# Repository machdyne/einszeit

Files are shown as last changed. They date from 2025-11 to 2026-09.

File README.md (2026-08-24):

# Einszeit

Einszeit is an open-source security device intended to provide information-theoretically secure (one-time-pad based) encryption between two or more paired devices over any communications medium.

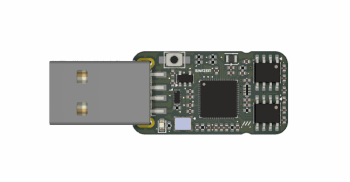
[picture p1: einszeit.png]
Einszeit


> **Project status:** V1 hardware is in active development. See [Hardware Status](#hardware-status) and [Software Status](#software-status) below before using this project for anything beyond bench testing.

## Hardware Status

| Version | Status |
|---|---|
| V0 | **Deprecated.** Based on the ATSHA204A secure element. See [Why V0 was deprecated](#why-v0-was-deprecated). No longer maintained or recommended for use. |
| V1 | **Design complete, not yet fabricated.** Redesigned around the RP2350 microcontroller. Boards have not yet been fabricated, bench validated, entropy-tested, or used to generate production key material. |

### Why V0 was deprecated

V0 relied on the ATSHA204A secure element's `Random` command as its sole entropy source. While this was suitable for a functional prototype, it is not a raw entropy tap — it is the output of an internal DRBG (deterministic random bit generator) seeded periodically from a physical noise source. This means:

- Output entropy is bounded by the (infrequently refreshed) internal seed, not by the number of bytes read out.
- The construction is architecturally unsuited to one-time-pad key material, which requires each output bit to carry close to full entropy.
- The DRBG design is closed and proprietary, offering no way to independently validate its internal construction. (still true on V1 unfortunatey)

### V1 architecture (hardware)

V1 is built around the **RP2350** microcontroller, chosen primarily for its documented, dedicated TRNG peripheral.

- **Entropy source:** RP2350's built-in TRNG block (Arm IP), which samples an internal free-running ring oscillator and claims compliance with FIPS 140-2, BSI AIS-31, and NIST SP 800-90B. Nominal entropy rate is ~7.5 kb/s at 150 MHz core clock.
- **Key storage:** key material now never leaves the device and can now be exchanged on a microsd card

A secondary, physically independent entropy source (e.g. a discrete noise circuit) is not currently planned, but remains a possible future defense-in-depth addition if the RP2350 TRNG's characteristics warrant it.

Full entropy source documentation, extraction method, and validation results will be published alongside V1 firmware.

## Software Status

The `ez` utility (originally written against V0's alice/bob device model) is **not yet compatible with V1**.

- V1 introduces a **multi-key model**, replacing the fixed alice/bob key-pair scheme with support for multiple paired devices and key slots.
- `ez` will require updated firmware-side commands and a corresponding rewrite of its identity, key-copy, and read/write logic to address multiple key slots rather than a single fixed pair.
- New V1 firmware (implementing the TRNG-based generation pipeline and multi-key metadata format) is in progress and not yet released.

## Security Model

Einszeit's core claim is that, given genuine full-entropy key material and correct one-time use, message confidentiality is information-theoretically secure — i.e., secure regardless of an adversary's computational power. This claim depends entirely on:

1. The entropy source(s) actually delivering full min-entropy per output bit (not merely passing statistical randomness tests, which a well-built DRBG would also pass).
2. Conditioning/extraction functions that don't reintroduce a computational-hardness dependency where an information-theoretic one is claimed (e.g., preferring universal-hash/Leftover-Hash-Lemma-based extraction over hash-based conditioning where the strict claim matters).
3. Correct one-time use of key material and secure erasure after use.

## AI Disclosure

This project makes use of LLMs for documentation, specifications, firmware and software. Once the project is stable, a human audit will be performed resulting in a code freeze that must not be directly modified by any LLM without an additional human audit.

## Funding

This project was partially funded through the NGI0 Commons Fund, a fund established by NLnet with financial support from the European Commission's Next Generation Internet programme.

## License

The contents of this repo are released under the [CERN-OHL-P](LICENSE.txt) license with the following exceptions:

 * The ch32fun library is MIT licensed.
 * The hidapi library is BSD licensed.

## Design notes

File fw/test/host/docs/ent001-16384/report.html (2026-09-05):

# Einszeit V1 hardware validation

conditioned.bin · 100,800,000 bits · conditioned mode

Device 9bae095b4556f8f4 · RP2350 OTP CHIPID, unique per die

0.8791

bits of min-entropy per captured bit
Compression is the limiting estimator

01.0, a perfect binary source

At this rate, one byte of one-time-pad key needs 9.1 bits (1.14 raw bits per key bit) fed through a conditioning function that preserves min-entropy.

Capture mode

conditioned

SP 800-90B

0.8791 bit/bit

SP 800-22

15/15 pass, 1 marginal

AIS-31 (2011)

all pass

FIPS 140-2 4.9.1

5040 blocks

This capture is the conditioned TRNG output. Passing statistical tests on conditioned data says very little: a correctly seeded DRBG passes all of them too. The min-entropy figure above is an upper bound on what the post-processing preserved, not a measurement of the physical source. Use a raw capture for the entropy claim.

## Entropy assessment

Assessed over 8,000,000 bits using the non-IID track of SP 800-90B. The reported min-entropy is the smallest of the ten estimators, which is what the specification requires.

Each estimator bounds min-entropy from above in its own way; the assessment takes the most pessimistic.

Each estimator bounds min-entropy from above in its own way; the assessment takes the most pessimistic.

Estimator | Hmin | Note
Most Common Value | 0.9984
Collision | 0.9753
Markov | 0.9970
Compression | 0.8791
t-Tuple | 0.9295
LRS | 0.9982
MultiMCW | 0.9992
Lag | 0.9980
MultiMMC | 0.9989
LZ78Y | 0.9989

Assessed on the first 8,000,000 bits of a 100,800,000-bit capture. SP 800-90B asks for at least 1,000,000 samples and the predictors scale badly beyond a few million; SP 800-22 below was run over the full capture. Override with --entropy-bits.

The Compression estimator is limiting, but it is reporting at its ceiling for this sample size. Running the same estimator over an ideal uniform sample of 8,000,000 bits scores 0.8807 ± 0.0113 (mean of 5 runs), against 0.8791 measured. The gap of 0.0016 is within normal run-to-run spread, so at this length the estimator cannot report higher and this figure reflects the estimator rather than the source. Capture more to raise the ceiling.

### Independence indicators

Check | Statistic | p
Chi-square goodness of fit | 9.92 | 0.3567
Chi-square independence | 4.91 | 0.0857
Longest repeated substring | 44 | expected 45.9

consistent with IID. These indicators can reject IID but cannot establish it. A formal IID claim requires the 10,000-permutation test from SP 800-90B 5.1, which is not reimplemented here.

## Distribution and structure

Measure | Value | Reference
Capture size | 12,600,000 B | 100,800,000 bits
Proportion of ones | 0.500006 | 0.5
Bit bias | +0.000006 | 0
Shannon entropy per bit | 1.000000 | 1.0
Shannon entropy per byte | 7.999978 | 8.0
Min-entropy per byte, most common value | 7.9805 | 8.0
Byte chi-square | 377.6 | 255 ± 23, p = 0.0000
Arithmetic mean of bytes | 127.4730 | 127.5
Monte Carlo π | 3.14299 | error 0.045%
Serial correlation | -0.000795 | 0
Longest run of ones / zeros | 25 / 23 | ~27
Compressed size (zlib / bz2 / lzma) | 1.0003 / 1.0050 / 1.0001 | ≥ 1.0

Visual inspection. Any visible texture, banding or repetition is a defect that the numeric tests may not isolate.

Visual inspection. Any visible texture, banding or repetition is a defect that the numeric tests may not isolate.

Byte value distribution against the uniform expectation.

Byte value distribution against the uniform expectation.

Bias by position inside one 192-bit entropy-holding-register read. A repeating shape here points at the collection mechanism rather than the ring oscillator.

Bias by position inside one 192-bit entropy-holding-register read. A repeating shape here points at the collection mechanism rather than the ring oscillator.

Autocorrelation at short lags. A spike at a fixed lag usually means the sampling interval is short enough that consecutive samples share oscillator phase.

Autocorrelation at short lags. A spike at a fixed lag usually means the sampling interval is short enough that consecutive samples share oscillator phase.

Power spectrum. Peaks indicate periodic structure, often from a clock beating against the ring oscillator.

Power spectrum. Peaks indicate periodic structure, often from a clock beating against the ring oscillator.

Run lengths against the 2^-k ideal.

Run lengths against the 2^-k ideal.

Entropy across the capture, in order.

Entropy across the capture, in order.

## Standards conformance

### NIST SP 800-22 Rev 1a, 100 sequences

This is the governing SP 800-22 result: the suite partitioned into 100 sequences of 1,008,000 bits, scored by the proportion of sequences passing. Tests that emit several p-values per sequence are scored per sub-test, as the specification intends; the count column shows how many, and the proportion shown is the worst of them.

Test | sub | worst | proportion vs bound | Result
Approximate entropy | | 100/100 | 1.000 vs 0.960 | pass
Binary matrix rank | | 99/100 | 0.990 vs 0.960 | pass
Block frequency | | 100/100 | 1.000 vs 0.960 | pass
Cumulative sums | 2 | 100/100 | 1.000 vs 0.960 | pass
DFT (spectral) | | 99/100 | 0.990 vs 0.960 | pass
Frequency (monobit) | | 100/100 | 1.000 vs 0.960 | pass
Linear complexity | | 100/100 | 1.000 vs 0.960 | pass
Longest run of ones | | 99/100 | 0.990 vs 0.960 | pass
Maurer universal | | 100/100 | 1.000 vs 0.960 | pass
Non-overlapping template | 10 | 97/100 | 0.970 vs 0.960 | pass
Overlapping template | | 100/100 | 1.000 vs 0.960 | pass
Random excursions | 8 | 62/64 (36 seq n/a) | 0.969 vs 0.953 | pass
Random excursions variant | 18 | 63/64 (36 seq n/a) | 0.984 vs 0.953 | pass
Runs | | 96/100 | 0.960 vs 0.960 | marginal
Serial | 2 | 97/100 | 0.970 vs 0.960 | pass

Marginal: Runs. The shortfall is smaller than one sequence, which is the integer coarseness of the acceptance bound rather than evidence of a defect.

### Single-sequence pass over the first 20,000,000 bits

A second, independent run of the same suite treating the first 20,000,000 bits as one sequence. It is not the conformance result; it is kept because a single long sequence has more statistical power than any individual sequence above, so it can surface a small consistent deviation that the per-sequence view absorbs. Disagreement between the two is expected and is not a contradiction.

Test | p | Result
Frequency (monobit) | 0.9797 | pass
Block frequency | 0.9914 | pass
Runs | 0.0000 | fail
Longest run of ones | 0.8280 | pass
Binary matrix rank | 0.9651 | pass
DFT (spectral) | 0.7257 | pass
Non-overlapping template | 0.5223 | pass | 10 p-values, min 0.0218
Overlapping template | 0.4007 | pass
Maurer universal | 0.9706 | pass
Linear complexity | 0.8327 | pass
Serial | 0.7001 | pass | 2 p-values, min 0.7001
Approximate entropy | 0.4107 | pass
Cumulative sums | 0.9298 | pass | 2 p-values, min 0.9131
Random excursions | 0.4293 | pass | 8 p-values, min 0.0795
Random excursions variant | 0.6374 | pass | 18 p-values, min 0.0923

p-values from the single-sequence pass; they should scatter roughly uniformly over (0,1).

p-values from the single-sequence pass; they should scatter roughly uniformly over (0,1).

Runs failed the single-sequence pass above but not the 100-sequence assessment. Test power grows with sequence length, so a small consistent deviation can sit inside the threshold on each shorter sequence and clear it over a longer one. The conformance verdict follows the multi-sequence result; the disagreement is recorded here because it is the more sensitive of the two and is worth investigating even when conformance is met.

### BSI AIS-31

Proc | Test | Value | Accept | Result
A | T0 disjointness | 65536.000 | 65536 – 65536 | pass
A | T1 monobit | 9984.000 | 9654 – 10346 | pass
A | T2 poker | 9.843 | 1.03 – 57.4 | pass
A | T3 runs | — | | pass
A | T4 long run | 16.000 | 0 – 33 | pass
A | T5 autocorrelation | 2553.000 | 2326 – 2674 | pass
B | T6 uniform distribution | 0.503 | 0.475 – 0.525 | pass
B | T7 comparative multinomial | 248.512 | | pass
B | T8 entropy (Coron) | 7.999 | 7.976 – 8 | pass

Implements AIS 31 v2.0 (2011). BSI's AIS 20/31 v3.0 (2024) restructures these procedures; a v3.0 evaluation needs different tests.

### FIPS 140-2 section 4.9.1

Across 5,040 blocks of 20,000 bits. A few blocks fall outside the intervals by chance on any source, so each subtest is judged on whether its failure count matches the expected false-positive rate.

Test | blocks failed | expected | p | Result
monobit | 1 | 0.5 | 0.396 | pass
poker | 1 | 0.5 | 0.396 | pass
runs | 0 | 1.8 | 1.000 | pass
long_run | 0 | 1.0 | 1.000 | pass

FIPS 140-2 4.9.1 is a power-up self-test on a single 20,000-bit block. Applied across a large capture, a few blocks fall outside its intervals by chance, so each subtest is judged on whether its failure count matches the expected false-positive rate rather than on a clean sweep. Removed from FIPS 140-2 by the 2002 change notice and absent from FIPS 140-3.

## SEC-TEST-ENT-001 conformance

EZ-SEC-001 requires the SP 800-22 suite, all fifteen tests, to be run against at least 100,000,000 bits of TRNG output for each hardware revision. This analysis is satisfied by this analysis.

Requirement | Result | Measured
At least 100,000,000 bits of TRNG output | met | 100,800,000 bits
All 15 tests executed | met | 15 of 15 produced a result
All tests pass | met | all pass
Proportion criterion meaningful (m >= 100) | met | 100 sequences
p-value uniformity applicable (m >= 50) | met | 100 sequences

This is a conformance statement from an independent reimplementation of SP 800-22. For the formal record, run NIST's sts-2.1.2 against the archived capture and cite that result; see EZ-TEST-DEVIATIONS.md G-04.

## Board subsystems

### Pin integrity

Each pin read with the internal pull-up then the internal pull-down engaged. A pin with an external pull-up reads high in both states, because 10K or 20K overwhelms the RP2350's ~55K internal pull-down. That is how the external resistors are confirmed present.

Pin | Net | pull-up | pull-down | Result
GPIO18 | FRAM_SCLK | 1 | 0 | pass
GPIO19 | FRAM_MOSI | 1 | 0 | pass
GPIO20 | FRAM_MISO | 1 | 0 | pass
GPIO21 | FRAM_SS | 1 | 1 | pass
GPIO25 | SD_DET | 1 | 1 | pass
GPIO26 | SD_SCLK | 1 | 1 | pass
GPIO27 | SD_MOSI | 1 | 1 | pass
GPIO28 | SD_MISO | 1 | 1 | pass
GPIO29 | SD_CSN | 1 | 1 | pass
GPIO12 | LED | 1 | 0 | pass

### Clocks

Clock | Configured | Measured
clk_sys | 150.000 MHz | 150.000 MHz
clk_peri | 48.000 MHz | 48.000 MHz
clk_usb | 48.000 MHz | 48.000 MHz
XOSC | — | 12.000 MHz
ROSC | — | 44.035 MHz
LPOSC | — | 33 kHz
XOSC stable | — | yes

### Always-on timer

Tick source | internal LPOSC (untrimmed ~32 kHz)
Running | yes
Measured error | 19799.2 ppm over 5000 ms

The RP2350 has no RTC block; this is the POWMAN always-on timer. When its tick comes from the same 12 MHz crystal as the system timer, the error above measures the divider and not the crystal, so it will read near zero regardless of crystal accuracy. Only a comparison against an external reference characterises the crystal itself.

### FRAM

present | True
rdid_supported | False
wel_toggles | True
miso_alive | True
id | 000000000000000000
vendor | unknown
part | unknown
density_bytes | 0
sr_idle | 0
sr_wren | 2
sr_wrdi | 0
test_ok | True
test_id_ok | False
test_sr_ok | True
test_bus_ok | True
test_patterns_ok | True
test_addressing_ok | True
test_bytes_tested | 28672
test_errors | 0
test_first_error_addr | 0

### microSD

ok | True
step | 9
step_name | ready
last_r1 | 0
acmd41_iterations | 3
init_ms | 8
type | SDHC/SDXC
capacity_bytes | 31666995200
blocks | 61849600
ocr | 0xc0ff8000
oid
pnm | APPSD
psn | 0x12800000
mdt | 2012-04

## Provenance

This capture is characterisation data and must not be used as key material. It was produced by bench firmware that bypasses the TRNG health tests, and it has crossed a USB link to this host. EZ-SEC-001 SEC-ENTROPY-001 requires key bytes to come exclusively from the TRNG on the device, and SEC-DIST-001 prohibits electronic transmission of key material.

Identifier | Value | Notes
Device UUID | 9bae095b4556f8f4 | RP2350 OTP CHIPID0..3, a 64-bit identifier programmed at manufacture. Read through the ROM get_sys_info call, so it identifies the die and not the flash part. The datasheet treats it as a public device ID.

The block below is telemetry the device recorded alongside the capture itself: die temperature, system clock, TRNG configuration and health-test counters. It travels inside every capture and is present whether or not the subsystem tests were run.

Everything above derives from the capture described here. Re-running the analysis on the archived .bin reproduces this report exactly.

{
  "key_material": false,
  "usage": "TEST ONLY - characterisation data, MUST NOT be used as key material (EZ-SEC-001 SEC-ENTROPY-001, SEC-DIST-001)",
  "fw": "einszeit-hwtest",
  "version": "1.4.0",
  "kind": "capture",
  "mode": "conditioned",
  "device_uuid": "9bae095b4556f8f4",
  "board_id": "9bae095b4556f8f4",
  "rosc_len": 0,
  "sample_cnt": 16384,
  "bypass_vnc": false,
  "bypass_crngt": false,
  "bypass_autocorr": false,
  "bytes": 17088,
  "collections": 712,
  "vn_err": 0,
  "crngt_err": 8,
  "autocorr_err": 0,
  "resets": 0,
  "timeouts": 0,
  "elapsed_us": 60296821,
  "bits_per_sec": 2267.18,
  "temp_c_start": 32.29,
  "temp_c_end": 32.29,
  "clk_sys_hz": 150000000,
  "rows": 0,
  "row_bytes": 0,
  "rounds": 65,
  "total_bytes": 12600000,
  "concatenated": true,
  "_container": {
    "declared_crc32": "0x00000000",
    "computed_crc32": "0x00000000",
    "crc_ok": true,
    "payload_bytes": 12600000
  }
}

### What this report does not establish

- The estimators here are an independent reimplementation of SP 800-90B, not a validated one. A certification claim needs NIST's own EntropyAssessment tool against the same archived capture.
- Restarts are triggered by TRNG_SW_RESET rather than by power-cycling the noise source, which is weaker than the specification intends.
- Entropy was measured at one supply voltage and one die temperature. A source that is healthy at room temperature can degrade at the edges of its range; characterise across the intended operating envelope before trusting it with key material.
- The TRNG is closed Arm IP. No amount of output testing can rule out a construction that is deterministic in a way the tests cannot see. This is the same limitation the project documentation notes for V0.

Generated 2026-09-05 10:02:33 CEST by einszeit-hwtest. Capture CRC-32 verified end to end from device to this report.

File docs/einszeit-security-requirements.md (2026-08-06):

# Einszeit Security Requirements Specification

**Document ID:** EZ-SEC-001  
**Status:** Normative  
**Scope:** All Einszeit hardware, firmware, software, interfaces, and documentation

---

## 0. Foundational Principle

One-Time Pad (OTP) encryption provides **information-theoretic (perfect) secrecy** if and only if three invariants hold simultaneously:

1. **Key length ≥ plaintext length** — the key is never shorter than the data it encrypts.
2. **Key is truly random** — key material is generated from a true random source, not a PRNG.
3. **Key is never reused** — each key byte is consumed exactly once, across all sessions, devices, and time.

Any violation of any invariant completely and irrecoverably destroys secrecy. All requirements in this document exist to enforce these three invariants at every layer of the system.

> **Physical and host security scope:** This specification does not address attacks that require physical access to the device or a compromised host. If an attacker controls the host machine, they can read plaintext directly (e.g., via keylogger). While devices may have some physical security features, protection against such attacks is ultimately the user's responsibility.

> **Authentication scope:** This specification covers encryption and decryption only. Message authentication — verifying that a message was produced by the expected party — is out of scope. The Key ID is a coordination identifier, not a secret, and MUST NOT be used as an authenticator or as evidence of message origin.

---

## 1. Definitions

| Term | Meaning |
|---|---|
| **Key** | A block of OTP key material generated once, distributed physically, and consumed over its lifetime. Identified by a Key ID. |
| **Key ID** | A TRNG-generated unique identifier associated with a Key at creation time. Not a secret. Used to differentiate between multiple shared keys, and by the device to identify sessions locally. |
| **Session** | A device's local record of its use of a specific Key, referenced by Key ID. Stores the current offset, role, drive index, human-readable name, and session status. Each Key has exactly one session per device; multiple sessions on one device correspond to multiple distinct Keys. |
| **Session status** | A flag stored in the session record indicating the session's operational state. Valid values: `VALID` (healthy and operational), `QUARANTINED` (integrity check failed; locked pending user action), `EXHAUSTED` (all key bytes consumed). Additional implementation-defined states (e.g. for optional features) may exist; see EZ-IMPL-001. |
| **Role** | A per-session designation of `alice` or `bob`, determining which half of the key the party consumes. Alice consumes from offset 0; bob consumes from `key_length / 2`. The key generator defaults to alice; the recipient defaults to bob. |
| **OTP offset** | The byte position of the next unconsumed key byte within a Key. Stored per-session in metadata storage. |
| **Key data storage** | Non-volatile storage holding key material (e.g., flash or removable media). |
| **Metadata storage** | High-endurance non-volatile storage holding session state (offsets, IDs, names). Logically and physically separate from key data storage. |
| **Plaintext** | Data before encryption. |
| **Ciphertext** | `Plaintext XOR key_bytes_at_offset`. |
| **TRNG** | True Random Number Generator — hardware entropy source producing non-deterministic output. |
| **PRNG** | Pseudo-Random Number Generator — a software algorithm producing deterministic output from a seed. **Never** used to generate key material. |
| **DRNG** | Deterministic Random Number Generator — a hardware component that produces output deterministically from a seed, regardless of how the seed was obtained. Produces pseudo-random, not truly random, output. **Never** used to generate key material. |
| **CSPRNG** | Cryptographically Secure Pseudo-Random Number Generator — a software algorithm producing deterministic output from a seed, designed to be computationally unpredictable. **Never** used to generate key material. |
| **Party** | One of the two endpoints sharing a Key. |

---

## 2. Entropy and Key Generation

### 2.1 Source Requirements

- **SEC-ENTROPY-001:** Key bytes MUST be generated exclusively from a hardware TRNG. Key material MUST NOT contain contributions from DRNGs, PRNGs, or CSPRNGs, regardless of whether they are implemented in hardware or software.
- **SEC-ENTROPY-002:** The TRNG MUST produce a minimum of 8 bits of entropy per output byte. Post-generation statistical testing MUST be performed on every generated key before it is marked valid and made available for use (see §9.1). A key MUST NOT be marked valid unless it passes these tests. If testing fails, the key MUST be discarded and the generation event logged as failed.
- **SEC-ENTROPY-003:** TRNG output MUST NOT be conditioned or whitened by any algorithm that could introduce determinism. If hardware debiasing is applied, it MUST NOT reduce per-byte entropy below 8 bits.
- **SEC-ENTROPY-004:** The TRNG MUST fail safe: generation MUST halt and raise an auditable fault if the entropy source is detected as degraded or unavailable. The system MUST NOT fall back to any software source.

### 2.2 Generation Process

- **SEC-GEN-001:** Key bytes MUST be transferred from the TRNG to key data storage without buffering in volatile memory longer than necessary to write a single block. Volatile buffers MUST be cleared immediately after each write.
- **SEC-GEN-002:** Key data MUST be verified by read-back immediately after writing, within the same generation session.
- **SEC-GEN-003:** Each generation event MUST produce a new Key ID (TRNG-generated) and record a generation log entry (timestamp, Key ID, byte length, test results) in metadata storage. The log entry MUST record whether the key was marked valid or rejected.

### 2.3 Online Entropy Monitoring (Recommended)

Online monitoring during generation is not required if the firmware guarantees that no key can be marked valid without passing post-generation tests (SEC-ENTROPY-002). It is RECOMMENDED as a way to detect TRNG degradation early and minimise wasted generation time.

If implemented, online monitoring SHOULD apply at minimum the following tests on a rolling window, halting generation immediately on failure:

- Monobit frequency test (proportion of 1s in the window)
- Runs test (length of consecutive identical bits)
- Autocorrelation test (correlation of output with a shifted copy of itself)

---

## 3. Storage Architecture

The system uses two logically and physically distinct storage tiers with strictly separated roles:

| Tier | Contents |
|---|---|
| Key data storage | Key material — raw random bytes only; Key ID is associated out-of-band via filename or manual exchange |
| Metadata storage | Session records: Key ID, role, drive index, OTP offset, session status, human-readable name |

These tiers MUST NOT be swapped. Key material MUST NOT be written to metadata storage. Session metadata MUST NOT be written to key data storage.

### 3.1 Key Data Storage

- **SEC-STORE-001:** Key data storage MUST support erasure under firmware control. The firmware is solely responsible for all write and erase policies.
- **SEC-STORE-002:** Each Key MUST have a Key ID associated with it at creation time. The Key ID MUST be generated by the TRNG and MUST NOT be derived from or related to the key material bytes. The Key ID is conveyed out-of-band (via filename convention or manual exchange) and is not embedded in the key file. It is used to differentiate between multiple shared keys and to correlate key data with a session record in metadata storage.

### 3.2 Metadata Storage

Metadata storage MUST support byte-level or word-level writes with high endurance, making OTP offset updates atomic and efficient. The choice of medium is an implementation decision; the requirements below apply regardless.

- **SEC-META-001:** Each session record MUST contain at minimum: Key ID, role, drive index, key length, two OTP offset slots, an offset selector, session status, human-readable name, and a CRC or equivalent integrity check covering the entire record.
- **SEC-META-002:** OTP offset updates MUST be written atomically. Power loss during an update MUST leave the offset in either the pre-update or post-update state — never in a partially updated state.
- **SEC-META-003:** On every power-on, all session records MUST be read and their integrity verified before any session operation is permitted. A session with a corrupt record MUST be set to `QUARANTINED` and flagged to the user. It MUST NOT silently reset its offset.
- **SEC-META-004:** Before allocating a new session record, the firmware MUST verify that its address range does not overlap any existing session record. Allocation MUST be rejected if a conflict is detected.

### 3.3 OTP Offset Integrity

The OTP offset is the most security-critical piece of metadata. Its corruption or rollback directly enables key reuse.

- **SEC-PTR-001:** The OTP offset MUST be stored with integrity protection per SEC-META-001. A corrupt offset MUST be detected on read and MUST NOT be silently treated as zero or any other default value.
- **SEC-PTR-002:** The OTP offset MUST only advance forward. Any command or request to set an offset to a value less than or equal to its current verified value MUST be rejected and logged.
- **SEC-PTR-003:** The offset MUST be advanced and the update committed atomically before ciphertext is output. If the update cannot be verified, the operation MUST be aborted and no ciphertext output.

---

## 4. Key Distribution

- **SEC-DIST-001:** Keys MUST be distributed via physical transfer only. Electronic transmission of key material over any network is PROHIBITED.
- **SEC-DIST-002:** A Key SHOULD be shared between exactly one alice and one bob. Distributing to multiple bobs is possible but they MUST be treated as read-only recipients — multiple bobs share the same offset range and any bob encrypting from it would cause immediate key reuse and irrecoverable loss of secrecy for all recipients. In a multi-bob scenario, any bob can also impersonate alice by encrypting from alice's offset range, and other bobs have no way to detect this. More broadly, any party holding key material can misuse it in this way; limiting distribution limits exposure.
- **SEC-DIST-003:** Upon receiving a Key, the recipient SHOULD verify the Key ID matches the expected value before importing it into a session. Mismatches SHOULD be investigated before proceeding.
- **SEC-DIST-004:** Unintended duplication of a Key creates additional parties who can decrypt all messages encrypted under that Key. The system cannot prevent duplication; users are responsible for controlling how many copies of a Key exist.
- **SEC-DIST-005:** If a medium carrying a Key shows evidence of unexpected access or tampering, the user MUST be warned. The decision to proceed or discard is the user's.

---

## 5. Encryption and Decryption

### 5.1 Encryption Operation

- **SEC-ENC-001:** Encryption MUST be performed as `C[i] = P[i] XOR K[offset + i]` for each byte `i` of the plaintext, where `offset` is the current OTP offset for the session. The initial offset is role-dependent: alice starts at 0, bob starts at `key_length / 2`.
- **SEC-ENC-002:** The OTP offset MUST be advanced and committed before ciphertext is output (SEC-PTR-003).
- **SEC-ENC-003:** Plaintext MUST NOT be written to any persistent storage. Plaintext buffers in volatile memory MUST be cleared immediately after ciphertext is produced.
- **SEC-ENC-004:** The message header MUST include the OTP offset at which encryption began, so the receiver can locate the correct key bytes. The offset is not a secret. Whether to include a Key ID in the header is a protocol decision left to the implementation.

### 5.2 Decryption Operation

- **SEC-DEC-001:** Decryption MUST be performed as `P[i] = C[i] XOR K[offset + i]`, where `offset` is taken from the message header.
- **SEC-DEC-002:** If a Key ID is present in the message header, the receiver MUST verify it matches the session's Key before reading any key bytes. If no Key ID is present, session selection is the responsibility of the operator or higher-level protocol.
- **SEC-DEC-003:** Replay detection: the receiver MUST reject any message whose offset range overlaps a previously consumed range. Rejection MUST occur before any key bytes are read or output is produced.
- **SEC-DEC-004:** After successful decryption, the receiver's OTP offset MUST advance to `max(current_offset, message_offset + message_length)`.

### 5.3 Key Derivation Prohibition

- **SEC-KDF-001:** Key derivation functions, key stretching, or any algorithmic transformation of key material MUST NOT be used. Key bytes MUST be used directly as the key stream.

### 5.4 Session Isolation

- **SEC-ISO-001:** Key bytes from one session MUST NOT be accessible during an operation belonging to another session. The firmware MUST enforce session boundaries so that loading key bytes for session A never reads from the offset range of session B.
- **SEC-ISO-002:** It is PROHIBITED for two sessions on the same device to share the same Key ID. Importing a Key whose Key ID already exists in a session record MUST be rejected.

---

## 6. Transmission

- **SEC-TX-001:** Ciphertext MAY be transmitted over any channel. Channel confidentiality is not required.
- **SEC-TX-002:** The message header MUST carry the OTP offset (SEC-ENC-004). No plaintext, key material, or session state beyond what is required by the header MUST appear in transmitted data.

---

## 7. User Interface

- **SEC-UI-001:** The UI MUST display the remaining key capacity for each session. Remaining capacity is half the total key length minus bytes consumed, since each party (alice or bob) has access to only their half of the key. When remaining capacity falls below a configurable threshold (default: 20%), a persistent warning MUST be shown. When a session is fully exhausted, the UI MUST notify the user and mark the session inactive.
- **SEC-UI-002:** Plaintext MUST NOT be retained in any scrollback buffer, clipboard, or undo history after the user dismisses the message view.
- **SEC-UI-003:** The UI MUST require explicit user confirmation before any encryption operation that advances the OTP offset, to prevent accidental key consumption.
- **SEC-UI-004:** Quarantined sessions (SEC-META-003) MUST be visually distinguished from healthy sessions and MUST NOT be usable for encryption or decryption until the user explicitly resolves or deletes them.
- **SEC-UI-005:** OTP offset values and remaining key length MUST NOT appear in any log file or diagnostic output accessible to a remote party. Key IDs may appear in logs as they are not secret.

---

## 8. Hardware Design Requirements

- **SEC-HW-001:** All OTP operations (generation, encryption, decryption) MUST be performed on the dedicated Einszeit device. These operations MUST NOT be delegated to or performed on a host computer.
- **SEC-HW-002:** If removable media is used as key data storage during active sessions, its removal is equivalent to loss of key material for those sessions. The firmware MUST detect removal and MUST NOT continue an in-progress encryption or decryption operation after removal.
- **SEC-HW-003:** If key data storage and firmware storage share the same physical medium, they MUST occupy non-overlapping address regions. A firmware write or update operation MUST NOT be able to reach the key data region.

---

## 9. Firmware and Software Requirements

- **SEC-FW-001:** All firmware MUST be written in a memory-safe language, or all memory safety vulnerabilities MUST be identified and remediated by code review.
- **SEC-FW-002:** All variables holding plaintext or key bytes MUST be handled in a way that prevents compiler optimization from eliding clearing operations (e.g., `volatile`-qualified writes or explicit memory barrier calls in C).
- **SEC-FW-003:** Any memory region that held key bytes or plaintext MUST be cleared before it is reused for any other purpose.
- **SEC-FW-004:** The firmware MUST NOT expose a command, interface, or debug path that allows raw read access to key data storage. All key data access MUST go through the session management layer, which enforces offset advancement.

---

## 10. Testing Requirements

### 10.1 Entropy Testing

- **SEC-TEST-ENT-001:** TRNG output MUST pass the NIST SP 800-22 statistical test suite (all 15 tests) on a minimum sample of 10⁸ bits, performed on each hardware revision and after any modification to the entropy source.
- **SEC-TEST-ENT-002:** If online entropy monitoring is implemented (§2.3), it MUST be verified by injecting a known-bad (biased) byte stream and confirming it triggers halt within one rolling window.
- **SEC-TEST-ENT-003:** The AIS-31 (BSI) test suite MUST be applied to characterise the TRNG output on each hardware revision.

### 10.2 OTP Offset Tests

- **SEC-TEST-PTR-001:** A test harness MUST verify that offset advancement is monotonic under normal operation, simulated power loss at each stage of the metadata write sequence, and concurrent session access attempts.
- **SEC-TEST-PTR-002:** A test harness MUST verify that a corrupt session record (bit-flip injection into metadata storage) is detected on power-on and causes the session to be quarantined rather than silently used.
- **SEC-TEST-PTR-003:** A test harness MUST verify that offset rollback attempts (by command or simulated storage manipulation) are rejected.

### 10.3 Encryption Correctness Tests

- **SEC-TEST-ENC-001:** Known-answer tests (KATs) MUST be run on every firmware build: given a fixed key and plaintext, verify ciphertext byte-for-byte.
- **SEC-TEST-ENC-002:** A test MUST verify that encrypting the same plaintext at two different OTP offsets produces different ciphertexts.
- **SEC-TEST-ENC-003:** A test MUST verify that re-encrypting at the same offset is impossible because the offset has already advanced.

### 10.4 Session Isolation Tests

- **SEC-TEST-ISO-001:** A test MUST verify that importing a Key whose Key ID already exists in a session record is rejected (SEC-ISO-002).
- **SEC-TEST-ISO-002:** A test with two active sessions MUST verify that a read for session A never returns bytes from session B's offset range.

### 10.5 Replay Tests

- **SEC-TEST-REPLAY-001:** A test MUST verify that a message with a previously consumed offset range is rejected before any key bytes are read or output is produced.

### 10.6 Removable Media Tests

- **SEC-TEST-MEDIA-001:** A test MUST verify that removing key storage media during an in-progress operation causes the operation to be aborted cleanly, with no partial ciphertext output and no offset advancement recorded.

---

## 11. Requirements Traceability

Every implementation artifact (hardware schematic, firmware module, test case, user manual section) MUST reference the requirement IDs it satisfies. No requirement may be marked satisfied by documentation alone; each MUST be demonstrated by a passing test (§10) or a physical inspection record.

---

*End of EZ-SEC-001*

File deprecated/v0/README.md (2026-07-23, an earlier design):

# Einszeit

Einszeit is an open-source security device that can theoretically provide perfect quantum-proof encryption between two paired devices over any communications medium.

Einszeit

This repo contains schematics, PCB layouts, a 3D-printable case, firmware and documentation.

Find more information on the [Einszeit product page](https://machdyne.com/product/einszeit-security-device/).

*V0 has been deprecated; see V1.*

## Limitations

Some of the limitations may be improved through firmware updates.

  * Message generation is limited to ~2MB after each pairing.
  * Initial key generation takes several hours.
  * Paired devices must be distributed in person.
  * Crypto IC configuration is factory locked to enable RNG output.
  * Key is temporarily stored on your computer during pairing.
  * Device is limited to ~400K lifetime metadata updates.
  * Must copy key to one device at a time.
  * Lacks fundamental error checking.

## Usage

The `ez` utility can be used to configure the device identity, to generate and copy keys, and to read or write messages. It stores the key pointer on the device, incrementing it each time a message is written.

### Set device identity

This command initializes the device metadata and sets the device identity.

Each device in the pair is identified as either alice or bob. The metadata is stored in EEPROM. The device must be erased to change its identity.

If the identity is alice, this command will also generate both the alice and bob keys and save them as `ez.key` (this will take several hours).

```
$ ez -i <alice|bob>
```

### Copy keys

This command copies the key data to the connected device.

```
$ ez -c
```

### Write a message

The write command generates an encrypted base64-encoded message. The message will only be generated after the key pointer has been successfully incremented.

```
$ ez -w << plain.txt
```

or

```
$ ez -w
Type your message here.
^D
```

### Read a message

Use this command to read an encrypted base64-encoded message that was previously generated using the write command from a paired device.

```
$ ez -r << cipher.txt
```

or

```
$ ez -r
Paste the base64-encoded message here.
^D
```

Note: You can use `-v` to verify a message that you've written.

### Erase device

This peforms a factory reset by erasing the keys and metadata.

```
ez -E
```

### Random data

This command will generate 32 bytes of random data, it can be used to test the quality of the hardware random number generator with testrand.sh.

```
ez -R
```

## Implementation Details

### Metadata

The metadata is 32-bytes and is stored in one of 16 EEPROM data slots:

	magic[2] = 0x455a
    sequence[4] = highest value indiciates current slot
	send_ptr[4] = offset of next unused key location
	boot_cnt[4] = incremented each time the device is powered on
	identity[1] = (0x00 = alice, 0x01 = bob)
    reserved[16]
	crc[1] = crc8(metadata)

All metadata slots are scanned to find the latest valid slot, then written to (latest\_slot + 1) % 16 on update.

*Note: This is currently limited to 4 slots.*

### Key Storage

The alice key is stored in flash at 0x000000 and the bob key is stored at 0x200000.

### Message Format

Messages are generated in the following format:

```
base64 ( [ <key_ptr:32> <msg_len:32> <ciphertext:n> ] <crc32:32> )
```

Note that the key offset and message length are not encrypted.

## LLM-generated code

To the extent that there is LLM-generated code in this repo, it should be space indented. Any space indented code should be carefully audited and then converted to tabs (eventually).

## License

The contents of this repo are released under the [CERN-OHL-P](LICENSE.txt) license, with the following exceptions:

  * The ch32fun library is MIT licensed.
  * The hidapi library is BSD licensed.

Note: You can use these designs for commercial purposes but we ask that instead of producing exact clones, that you either replace our trademarks and logos with your own or add your own next to ours.

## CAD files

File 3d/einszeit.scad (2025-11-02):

/*
 * Einszeit Enclosure
 * Copyright (c) 2025 Lone Dynamics Corporation. All rights reserved.
 *
 * required hardware:
 *  - 1 x M2.5 x 10mm countersunk bolt
 *  - 1 x M2.5 nut
 *
 */
 
$fn = 30;

box_width = 19;
box_length = 37;
box_height = 10.5;
box_thickness = 2.0;

lid_thickness = 3;

cutout_width = 16.10;
cutout_length = 44;
cutout_height = 5.5;

cutout_usb_width = 12;

board_height = 1.4;

roundness = 2;

toladj = 0.25;

//ldp_board(-0.5);
translate([0,0,-0.5]) ldp_case();
//translate([0,0,-0.25]) ldp_endcap();

// m2.5 bolt
//translate([0,-13.5,-6.25]) color([1,0,0]) cylinder(d=2.5, h=12, $fn=36);

// m2.5 nut
//translate([0,-13.5,-6.55]) rotate(30) color([1,0,0]) cylinder(d=5.8, h=2.4, $fn=6);

module ldp_endcap()
{
    		 	
	difference() {
		union() {
			translate([0,-13.5,-0.5]) color([0,0,1]) cylinder(d=6, h=3.5, $fn=36);
			translate([0,-15.75,-0.25]) cube([16.1,5.5,6.5], center=true);
		}
		translate([0,-13.5,-4.25]) color([1,0,0]) cylinder(d=3, h=8, $fn=36);
        color([1,0,0]) translate([0,0,-5.5]) cube([6.5,100,6], center=true);

	}
}

module ldp_board(o)
{

	difference() {
		union() {
			translate([0,2,o])
				color([0.0,0.8,0.0]) cube([16, 26, 1.6], center=true);
			translate([0,23,o+1])
				color([0.9,0.9,0.9]) cube([12, 15, 4.5], center=true);
		}

	}
	
}

module ldp_case()
{

	difference() {
		
		minkowski() {
			cube([box_width-(roundness*2),box_length-(roundness*2),box_height-(roundness*2)],
				center=true);
			sphere(roundness);
		}	
        
		translate([0,-5,(box_height-cutout_height)/2-2])
			cube([cutout_width+toladj,cutout_length,cutout_height], center=true);

		translate([-5.675,-5,(box_height-cutout_height)/2-3])
			cube([5,cutout_length,cutout_height], center=true);
		
		translate([5.675,-5,(box_height-cutout_height)/2-3])
			cube([5,cutout_length,cutout_height], center=true);

		// USB cutout
        translate([0,15,0.8])
            cube([cutout_usb_width+toladj,10,4.6+toladj], center=true);
        
		// bolt hole
		translate([0,-13.5,-5]) cylinder(d=2.75+toladj, h=100, $fn=36);
		
		// nut cutout
		translate([0,-13.5,-5.75]) rotate(30) cylinder(d=6+toladj, h=2.5, $fn=6);
    
        // lid notch cutout
        translate([0,-13.5,4.5]) cylinder(d=5+toladj, h=100);

//        translate([-1.5,2.5,5.1]) rotate([0,0,270])
//            linear_extrude(0.3)
//                text("EINSZEIT", size=3.5, halign="center", font="Lato Black");

	}

}

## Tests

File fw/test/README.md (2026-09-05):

# fw/test — Einszeit V1 hardware validation

Bring-up firmware and analysis tooling for the Einszeit V1 board (RP2350A).
Validates the HRNG, FRAM, microSD, clocks and board wiring, transfers entropy
captures over USB CDC with XMODEM-1K, and produces a report covering entropy
quality and the standards the RP2350 TRNG is claimed to meet.

> **This is a bench instrument, not a production artifact.** It deliberately
> bypasses the TRNG hardware health tests and exposes storage test paths. Never
> flash it to a device holding key material, and never include it in a build
> that generates key material. See `docs/EZ-TEST-DEVIATIONS.md`.

## Compliance status against EZ-SEC-001

This artifact is **not fully compliant, by design**. Three requirements are
deliberately inverted because inverting them is the tool's function: you cannot
characterise a noise source whose health tests halt it, and you cannot assess
raw entropy that has already been debiased.

- `docs/EZ-TEST-TRACEABILITY.md` — every requirement ID, its disposition, and
  the evidence for each satisfied row, per EZ-SEC-001 §11. Includes the
  SEC-FW-001 code review record.
- `docs/EZ-TEST-DEVIATIONS.md` — five deviations (D-01 … D-05) and six gaps
  (G-01 … G-06), each with a containment measure or an action.

Three gaps block a compliant *product*, not this tool: **G-04** (SP 800-22 at
10⁸ bits), **G-05** (online monitoring and per-key acceptance testing) and
**G-06** (the §10.2–10.6 harnesses, which need the session layer to exist).

The main control added by the audit is `src/ez_guard.c`: the firmware refuses
every storage read, write and erase path unless the FRAM is demonstrably blank
or carries this tool's own marker. On V1 the FRAM is metadata storage, holding
the OTP offsets. A bench tool that can roll an offset backwards causes silent
key reuse — the one failure EZ-SEC-001 §0 calls irrecoverable.

```
ez> fram test
refused: fram test

This board's FRAM holds data that is neither blank nor this tool's own test
marker. On a provisioned Einszeit device the FRAM is metadata storage: it holds
the OTP offsets that record how much of each Key has been consumed.
...
```

On a genuinely bare board, `guard claim` writes the marker and storage tests
become available.

## Layout

```
CMakeLists.txt      standalone or add_subdirectory(test) from fw/
include/  src/      firmware
host/               Python analysis and report tooling
docs/               EZ-SEC-001 audit records
```

## Build

```bash
mkdir build && cd build
PICO_SDK_PATH=/path/to/pico-sdk cmake .. -DCMAKE_BUILD_TYPE=Release
make -j
```

Or from `fw/CMakeLists.txt`, after the parent has called `pico_sdk_init()`:

```cmake
add_subdirectory(test)
```

Builds clean under `-Wall -Wextra`, which is part of the SEC-FW-001 evidence.
`-DEZ_ENABLE_RAW_STORAGE_DUMP=ON` re-enables the raw dump paths and knowingly
violates SEC-FW-004 and SEC-UI-005; CMake warns when you do it.

### Firmware update mode

Three ways in, no button needed for the first two:

```bash
python3 ez_validate.py bootsel --port /dev/ttyACM0   # from the host
```
```
ez> reboot bootsel                                    # from the device shell
```
```bash
picotool reboot -f -u                                 # works even if the shell hangs
```

`picotool` works without any cooperation from the firmware because the build
sets `PICO_STDIO_USB_ENABLE_RESET_VIA_VENDOR_INTERFACE=1`, which exposes a
reset endpoint alongside the CDC interface.

The board then enumerates as RPI-RP2 mass storage; copy
`build/einszeit_hwtest.uf2` to it, or `picotool load -x build/einszeit_hwtest.uf2`.
The status LED on GPIO12 keeps blinking in the bootloader as an activity
indicator, so you can tell the board is alive rather than hung.

Holding the BOOTSEL button while plugging in still works as the fallback.

Note that the card-detect policy and the storage guard release are held in RAM
only, so both revert on reboot. Re-apply them after an update, or make them
permanent in `board.h`.

## Run

```bash
cd host && pip install -r requirements.txt
./ez_validate.py selftest                  # check the tooling first
./ez_validate.py ports
./ez_validate.py all --port /dev/ttyACM0 --out runs/board-01
```

Produces `runs/board-01/report.html` (self-contained), `report.json`, and the
raw `.bin` captures so the analysis can be re-run or handed to NIST's tools.
A first pass takes about 15 minutes, most of it waiting on the TRNG.
`--sweep` and `--restart` add hours.

## Commands

```
help                            command list with capture examples
info [--json]                   chip, board id, clocks, die temperature
pins [--json]                   external pull-up verification (no SD card fitted)
guard [claim] [--json]          storage access policy; claim marks a blank board
led on|off|blink

clock [--json]                  clock tree, configured against measured
clock aon [ms] [--json]         always-on timer source and drift

fram id [--json]                JEDEC ID, vendor/part decode, status register
fram size [--json]              density by address aliasing        [guarded]
fram test [bytes] [--full]      patterns and address uniqueness     [guarded]
fram bench [bytes]              throughput at seven SPI clocks      [guarded]
fram dump <addr> <len>          disabled by default (SEC-FW-004, SEC-UI-005)
fram write <addr> <hex>                                             [guarded]

sd det [--watch]                card-detect level and transitions
sd init | sd info [--json]      SPI bring-up, CID/CSD decode        [needs card]
sd read <lba>                   read and CRC-verify; contents withheld
sd bench [blocks]               throughput and CRC errors           [needs card]
sd write <lba> --yes            destructive block write             [guarded]

hrng info [--json]              every TRNG register, decoded
hrng cfg [rosc N] [sample N] [raw|cond]
hrng health [n] [--json]        throughput and health-test error counters
hrng cap <bytes> [raw|cond] [rosc N] [sample N]
hrng sweep [collections] [raw]  chain length x sample interval, CSV
hrng restart <rows> <bytes>     SP 800-90B restart matrix

buf [zero]                      buffer status; 'buf zero' wipes and verifies
dump [n]                        hex dump of the capture buffer
send                            transmit the buffer over XMODEM-1K
selftest [--json]               every subsystem in one pass
reboot [bootsel]
```

Every command ends with `[done rc=N]` so a host script can frame the output.
`--json` emits one `#JSON {...}` line. Long operations emit `# progress` lines
and abort on ESC. `[guarded]` commands require `ez_guard_permit_storage()`.

## Capture modes

`cond` leaves the Von Neumann balancer, continuous RNG test and autocorrelation
test enabled — the configuration production firmware would use.

`raw` sets all three bypass bits in `TRNG_DEBUG_CONTROL`, giving raw digitised
ring-oscillator samples. This is what SP 800-90B assesses, and is deviation
D-02 against SEC-ENTROPY-003.

Captures are framed in a 1024-byte header carrying the exact payload length, a
CRC-32, and JSON metadata including `"key_material": false`. The length matters
because XMODEM pads its last block with 0x1A and pad bytes must never reach an
entropy estimator.

## Reading the entropy number

The report leads with min-entropy per captured bit and what follows from it:
how many raw bits you need per bit of one-time-pad key. At 0.35 bit/bit, a byte
of key needs about 23 bits of raw capture through a min-entropy-preserving
conditioner.

Two things to expect:

- **The raw capture will look bad.** Bias and short-lag correlation are normal
  for a directly sampled ring oscillator. That is why the hardware has a Von
  Neumann balancer in front of it.
- **The compression estimator often reads lowest.** Its expected-value curve is
  nearly flat near maximum entropy, so the 99% confidence subtraction costs a
  lot at small sample sizes. It converges slowly. The report flags this when it
  is the limiting estimator.

`SAMPLE_CNT1` resets to 65535, giving roughly 2.3 kbit/s at 150 MHz — well below
the ~7.5 kbit/s in the project README. Production firmware will need a shorter
interval, and shorter sampling costs sample independence. `--sweep` measures
that trade across all four inverter chain lengths.

## If `fram id` reports nothing

Two causes, both handled since 1.1.1:

**RDID is not universal.** The original Fujitsu MB85RS64 family, including the
MB85RS64PNF on Blaustahl, has no Device ID command, so opcode 0x9F clocks out
all zeroes from a perfectly healthy part. `fram id` now probes by toggling the
write-enable latch (WREN/WRDI, read back through RDSR), which every SPI FRAM
supports, and reports `PRESENT` even when the ID is unavailable. Use
`fram size` to measure density directly.

**Running `pins` first used to break the bus.** The pin test switches each GPIO
to SIO to read it, and before 1.1.1 it did not restore the SPI function
afterwards, so every later FRAM transfer returned 0x00. Fixed; function,
direction and level are now saved and restored per pin.

## FRAM identification: RDID is not universal

`fram id` does **not** use the JEDEC Device ID command to decide whether the
part is present, because not every SPI FRAM has one. The original Fujitsu
MB85RS64 family (including the MB85RS64PNF used on Blaustahl) predates RDID
entirely: sending 0x9F clocks out nothing and the host reads all zeroes, which
looks identical to a dead bus.

Presence is established instead by toggling the write-enable latch: `WREN` must
set WEL in the status register and `WRDI` must clear it. Every SPI FRAM ever
made supports RDSR and WREN/WRDI, the test is non-destructive, and it proves
the bus works in both directions. RDID is still read and reported when the part
answers, but its absence is reported as a property of the part, not a fault.

On a part without RDID, density cannot be read from the ID either. Use
`fram size`, which measures it directly by address aliasing. An MB85RS64 should
report 8192 bytes with 2-byte addressing.

`fram bench` sweeps to 32 MHz. The MB85RS64 family is rated to 20 MHz and the
V/B/T generations to 25-33 MHz, so verification failures at the top of the
sweep are the datasheet limit, not a board fault.

## When commands return rc=3

rc=3 is a policy refusal, not a hardware failure. Two policies can produce it.

**The storage guard** refuses FRAM and SD writes unless the FRAM is blank or
carries this tool's test marker. A board that this tool wrote patterns to in an
earlier session scans as occupied and locks itself out. Release it:

```bash
python3 ez_validate.py guard --port /dev/ttyACM2 --release
# or during a run:
python3 ez_validate.py collect --port ... --out runs/rN --allow-storage
# or on the device:
ez> guard claim --force --no-key-material
```

**Card detect** refuses SD commands when no card is seen. Not every microSD
socket has a detect switch, and polarity varies. `sd det` now classifies the
net by reading it with the internal pull-up and then the pull-down:

```
SD_DET (GPIO25)   : 1 with internal pull-up, 0 with pull-down
net               : floating: nothing is driving it
policy            : active-low
card present      : no
```

Floating with a card inserted means no usable detect line on this board:

```bash
python3 ez_validate.py guard --port /dev/ttyACM2 --sd-detect ignore
# or during a run: collect --sd-detect ignore
# or on the device: sd det ignore
```

Reading 0 with both pulls means something holds the pin at ground: with a card
in, that is an active-low switch (`sd det low`); with no card in, a normally
closed one (`sd det high`). Once you know, set `SD_DET_ACTIVE_LOW` in
`board.h` to make it the default.

EZ-SEC-001 SEC-HW-002 wants media removal to abort an operation in progress, so
`ignore` is a bench setting only. It must not be the default in firmware that
handles key material.

## Throughput and the SAMPLE_CNT1 decision

Conditioned throughput is fully determined by two things:

```
raw sample rate   = clk_sys / (SAMPLE_CNT1 + 1)
conditioned rate  = raw / 4      (Von Neumann emits ~1 bit per 4 raw bits)
```

At the SAMPLE_CNT1 **reset value of 65535** and clk_sys = 150 MHz that is
2.3 kbit/s raw and about 572 bit/s conditioned. The reset value is a power-on
default, not a recommendation, and it is far too slow for bulk key generation:

| SAMPLE_CNT1 | raw | conditioned | 1 MB takes |
| --- | --- | --- | --- |
| 65535 (reset) | 2.3 kbit/s | 572 bit/s | 4.1 hours |
| 16384 | 9.2 kbit/s | 2.3 kbit/s | 61 min |
| 4096 | 36.6 kbit/s | 9.2 kbit/s | 15 min |
| 1000 | 150 kbit/s | 37 kbit/s | 3.7 min |
| 256 | 584 kbit/s | 146 kbit/s | 1 min |

The ~7.5 kbit/s figure in the project README corresponds to SAMPLE_CNT1 near
5000.

**Shorter sampling is not free.** The entropy in each bit comes from ring
oscillator phase noise accumulated between sample points, so sampling faster
means less accumulated jitter per sample and more correlation between adjacent
samples. The right value is the smallest one at which the *conditioned* output
still measures 8 bits of entropy per byte, which is what EZ-SEC-001
SEC-ENTROPY-002 requires. `hrng sweep` plus the SP 800-90B analysis is how you
find it. Do not pick it by arithmetic.

**Do not copy the SDK's settings.** Raspberry Pi's own `pico_rand` sets
`SAMPLE_CNT1 = 0` and `TRNG_DEBUG_CONTROL = -1u`, streaming raw ROSC samples
with every decorrelator bypassed. Their comment says why that is acceptable
*for them*: "More temporal resolution to measure ROSC phase noise is better,
if we use a high quality hash function instead of naive VN decorrelation."
They mix the raw samples through a software hash. Einszeit cannot: SEC-ENTROPY-001
forbids CSPRNG contributions to key material and SEC-KDF-001 forbids
algorithmic transformation of it. Einszeit has to get full entropy out of the
hardware path alone, which means the Von Neumann corrector stays on and
SAMPLE_CNT1 has to be long enough to earn it.

One idea worth borrowing: `pico_rand` modulates `TRNG_CONFIG` (the inverter
chain length) with random bits "to reduce chance of injection locking". That is
a cheap defence against an attacker pulling the ring oscillator to a nearby
frequency, and it belongs in production generation firmware.

### Continuous vs cycled sampling

From v1.2.0 the driver leaves the noise source running between EHR reads
(`continuous`, the default). Reading the last EHR word restarts collection
automatically, so stopping and restarting the source only adds latency —
about 9% at SAMPLE_CNT1 = 65535, and proportionally far more at short
intervals. `hrng cfg cycled` restores the old behaviour, which starts every
192-bit block from the same source state and is the more conservative choice
when comparing blocks across a sweep.

## Two things still guessed

**`SD_DET` polarity** is assumed active-low in `board.h`. Confirm with
`sd det --watch` and correct `SD_DET_ACTIVE_LOW`. Gap G-02 depends on this.

**The clock.** RP2350 has no RTC, only the POWMAN always-on timer, so
`clock aon` handles all three tick sources and reports which is live. When the
tick derives from the same crystal as the system timer, the measured error
characterises the divider, not the crystal. If V1 carries a discrete RTC or a
32.768 kHz crystal, name the part and it can get a driver.

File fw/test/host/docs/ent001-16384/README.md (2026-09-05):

# Einszeit V1 entropy source characterisation data

## What this is

Raw and conditioned output from the RP2350 TRNG on an Einszeit V1 board,
captured for entropy source characterisation, together with the analysis
reports generated from it.

## What this is NOT

**This is not key material and must never be used as any.** Every capture is
tagged `"key_material": false` in its metadata. It was produced by bench
firmware that deliberately bypasses the TRNG hardware health tests, and it has
crossed a USB link to a host computer. EZ-SEC-001 SEC-ENTROPY-001 requires key
bytes to come exclusively from the TRNG on the device itself, and SEC-DIST-001
prohibits electronic transmission of key material.

The board these captures came from is a characterisation board. It has never
held key material and never will.

## Why it is published

The min-entropy figures in the reports were produced by an independent
reimplementation of the SP 800-90B estimators, not a validated one. Publishing
the underlying data is what makes those numbers checkable: anyone can run
NIST's own EntropyAssessment and sts-2.1.2 against these files and compare.

A claim about an entropy source that cannot be independently verified is not
worth much, particularly for a one-time-pad device whose entire security
argument rests on it.

## Files

`*.bin`      raw capture bytes, exactly as the device produced them
`*.json`     capture metadata: mode, SAMPLE_CNT1, inverter chain, health-test
             error counts, die temperature, board ID, throughput
`report.*`   generated analysis, HTML and machine-readable JSON
`SHA256SUMS` checksums tying the reports to the data they describe

`raw.bin` is the noise source with the Von Neumann balancer, the continuous RNG
test and the autocorrelation test all bypassed. It is expected to be biased;
that is what makes it the right input for an SP 800-90B assessment.
`conditioned.bin` is what production firmware would actually emit.

## Reproducing the analysis

```
git clone <this repo> && cd fw/test/host
pip install -r requirements.txt
python3 ez_validate.py analyze <this directory>/conditioned.bin --sequences 3
```

Or with NIST's validated tools:

```
ea_non_iid -i -a -v raw.bin 1        # SP 800-90B
assess 1000000 < conditioned.bin      # SP 800-22, sts-2.1.2
```

If your numbers disagree with the published reports, that is a finding worth
raising as an issue.

## Provenance

Captured from device UUID(s): `9bae095b4556f8f4`

This is the RP2350 OTP CHIPID, a 64-bit per-die identifier that the datasheet
describes as a public device ID. It is recorded so these captures can be tied to
the specific silicon that produced them.

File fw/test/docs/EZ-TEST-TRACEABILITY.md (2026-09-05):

# EZ-SEC-001 Traceability Matrix — Test Firmware

**Artifact:** `fw/test/` — Einszeit V1 hardware validation firmware and host analysis tooling
**Document ID:** EZ-TEST-TRACE-001
**Governing spec:** EZ-SEC-001 (Einszeit Security Requirements Specification)
**Status:** Audit record. Companion to `EZ-TEST-DEVIATIONS.md`.

---

## Summary

EZ-SEC-001 §Scope covers "all Einszeit hardware, firmware, software, interfaces,
and documentation", so this artifact is in scope. It is **not fully compliant,
and it must not be**. Three requirements are deliberately inverted because
inverting them is the tool's entire function: you cannot characterise a noise
source whose hardware health tests halt it, and you cannot assess raw entropy
that has already been debiased. Those inversions are recorded as deviations
D-02, D-03 and D-04 rather than as compliance.

Of the 51 requirement IDs in EZ-SEC-001:

| Disposition | Count | Meaning |
| --- | --- | --- |
| Satisfied | 9 | Implemented and demonstrated in this artifact |
| Supports | 6 | This artifact is the instrument by which a production requirement is measured |
| Not applicable | 27 | The artifact has no Key material, no session layer and no crypto path |
| Deviation | 5 | Deliberate, justified, mitigated — see `EZ-TEST-DEVIATIONS.md` |
| Gap | 4 | Cannot be met by this artifact as it stands — see `EZ-TEST-DEVIATIONS.md` |

The single most important control added by this audit is **`ez_guard.c`**: the
firmware refuses every storage read, write and erase path unless the FRAM is
demonstrably blank or carries this tool's own test marker. On Einszeit V1 the
FRAM is metadata storage, which holds the OTP offsets. A bench tool that can
overwrite or roll back an offset causes silent key reuse — the one failure mode
EZ-SEC-001 §0 says is irrecoverable.

§11 requires that no requirement be marked satisfied by documentation alone.
The Evidence column below names a passing test or an inspectable artifact for
every "Satisfied" row.

---

## §2 Entropy and Key Generation

| ID | Disposition | Evidence / rationale |
| --- | --- | --- |
| SEC-ENTROPY-001 | N/A + control | No key generation here. Control: every capture carries `"key_material": false` and a usage string naming this requirement (`write_capture_meta()`, `src/main.c`); the host report renders it as a warning banner (`host/ezlib/report.py`). |
| SEC-ENTROPY-002 | Supports | This artifact is how the 8 bits/byte figure gets measured. `host/ezlib/sp80090b.py` implements the SP 800-90B non-IID track; `ez_validate.py selftest` demonstrates no estimator overstates entropy on four sources of known entropy. Production per-key testing is **G-05**. |
| SEC-ENTROPY-003 | Deviation **D-02** | Raw mode sets all three bypass bits in `TRNG_DEBUG_CONTROL`, producing output well below 8 bits/byte by design. Never used as key material. |
| SEC-ENTROPY-004 | Deviation **D-03** | The tool continues past CRNGT, Von Neumann and autocorrelation faults instead of halting, and counts them. Counts appear in capture metadata and in the report. Conditioned mode leaves all health tests enabled. |
| SEC-GEN-001 | Deviation **D-04** | 192 KB of TRNG output is held in volatile memory for the duration of a capture. Mitigated by `ez_secure_zero()` on every buffer handover and the `buf zero` command. |
| SEC-GEN-002 | N/A | No key writes. The same read-back discipline is applied to the FRAM and SD tests (`ez_fram_test_region()`, `ez_sd_write_block()` + verify). |
| SEC-GEN-003 | N/A | No generation events. |
| §2.3 online monitoring | Supports | `hrng health` reports monobit-equivalent bias, runs behaviour and the hardware's own autocorrelation counters. Firmware-side rolling-window monitoring is production work; see **G-05**. |

## §3 Storage Architecture

| ID | Disposition | Evidence / rationale |
| --- | --- | --- |
| SEC-STORE-001 | Satisfied (negative) | This firmware performs no erase policy of its own on a provisioned device: `ez_guard_permit_storage()` refuses. Evidence: `guard --json` reports `storage_allowed:false` on any board whose FRAM is not blank or test-marked. |
| SEC-STORE-002 | N/A | No Key IDs are created. |
| SEC-META-001 | N/A | No session records. Format not yet defined; see **G-01**. |
| SEC-META-002 | N/A | No offset updates. |
| SEC-META-003 | Satisfied (negative) | The tool cannot cause a session record to be silently reset, because it refuses to write FRAM that it does not recognise as blank. `src/ez_guard.c`, `EZ_GUARD_OCCUPIED` path. |
| SEC-META-004 | N/A | No record allocation. |
| SEC-PTR-001 | N/A | No offsets read or written. |
| SEC-PTR-002 | Satisfied (negative) | `fram write`, `fram test`, `fram size` and `fram bench` — every path that could roll an offset backwards — are gated on `ez_guard_permit_storage()`. Inspect `src/main.c`, `cmd_fram()`. |
| SEC-PTR-003 | N/A | No ciphertext output. |

## §4 Key Distribution

| ID | Disposition | Evidence / rationale |
| --- | --- | --- |
| SEC-DIST-001 | Deviation **D-05** | Entropy captures cross a USB link to a host. They are characterisation data, not key material, and are tagged as such in the container metadata. |
| SEC-DIST-002/003/004/005 | N/A | No Key distribution. |

## §5 Encryption, Decryption, Derivation, Isolation

| ID | Disposition | Evidence / rationale |
| --- | --- | --- |
| SEC-ENC-001..004 | N/A | No encryption path exists in this artifact. |
| SEC-DEC-001..004 | N/A | No decryption path. |
| SEC-KDF-001 | N/A + note | No key derivation. Note: the SHA-256 and DCP blocks are never touched by this firmware, which is the posture SEC-KDF-001 wants preserved into production. |
| SEC-ISO-001/002 | N/A | No sessions. |

## §6 Transmission

| ID | Disposition | Evidence / rationale |
| --- | --- | --- |
| SEC-TX-001/002 | N/A | No ciphertext, no message headers. |

## §7 User Interface

| ID | Disposition | Evidence / rationale |
| --- | --- | --- |
| SEC-UI-001..004 | N/A | No session UI. |
| SEC-UI-005 | Satisfied | No OTP offset or key length can reach diagnostic output: raw FRAM dump is compile-time disabled (`EZ_ENABLE_RAW_STORAGE_DUMP=OFF` by default) and additionally guard-gated. `sd read` verifies the block CRC but withholds contents. Evidence: default build, `fram dump` returns rc=3 with a refusal citing SEC-UI-005. |

## §8 Hardware Design

| ID | Disposition | Evidence / rationale |
| --- | --- | --- |
| SEC-HW-001 | Satisfied | No OTP operation is delegated to the host. The host performs statistical analysis only, on data explicitly tagged as non-key material. |
| SEC-HW-002 | Partially satisfied | `ez_guard_sd_present()` refuses `sd init`, `sd read`, `sd bench` and `sd write` when no card is detected. Removal *during* a long operation is not detected: **G-02**. |
| SEC-HW-003 | Satisfied by architecture | Firmware lives in QSPI flash; key data storage on V1 is the microSD. Different media, no overlap possible. `CMakeLists.txt` records this. |

## §9 Firmware and Software

| ID | Disposition | Evidence / rationale |
| --- | --- | --- |
| SEC-FW-001 | Partially satisfied | C, so the "identified and remediated by code review" branch applies. A review was performed for this audit; three defects were found and fixed (see Code Review Record below). The tree builds clean under `-Wall -Wextra`. No static analysis, sanitizer or fuzzing coverage yet: **G-03**. |
| SEC-FW-002 | Satisfied | `ez_secure_zero()` uses `volatile` stores plus a compiler memory barrier, defeating dead-store elimination. `src/ez_secure.c`. |
| SEC-FW-003 | Satisfied | The capture buffer is cleared on every role change via `buffer_take_scratch()`, at nine call sites. `buf zero` performs a verified wipe. Before this audit the buffer was silently reused — see Code Review Record, finding 1. |
| SEC-FW-004 | Satisfied, with a build-time escape hatch | All storage access routes through `ez_guard_permit_storage()`. Raw dump paths are compiled out by default. With `-DEZ_ENABLE_RAW_STORAGE_DUMP=ON` the requirement is knowingly violated: **D-01**. CMake emits a warning in that configuration. |

## §10 Testing Requirements

| ID | Disposition | Evidence / rationale |
| --- | --- | --- |
| SEC-TEST-ENT-001 | Gap **G-04** | All 15 SP 800-22 tests are implemented (`host/ezlib/sp80022.py`) and demonstrated on uniform and biased sources. The 10⁸-bit sample size is not yet achievable in one run: the device buffer is 1.57 Mbit, so 64 capture rounds are needed, and the Python suite has not been profiled at that size. |
| SEC-TEST-ENT-002 | Gap **G-05** | Requires online monitoring to exist first. The host `selftest` does inject known-bad streams and confirms detection, which is the analysis-side half of this requirement. |
| SEC-TEST-ENT-003 | Satisfied | AIS-31 procedures A and B (T0–T8) implemented in `host/ezlib/standards.py`; verified against uniform data (all pass, Coron T8 = 7.9995) and biased data (T1, T2, T6 fail as expected). Caveat: implements AIS 31 v2.0 (2011), not v3.0 (2024). |
| SEC-TEST-PTR-001/002/003 | Gap **G-06** | Requires the metadata and session layer, which does not exist yet. |
| SEC-TEST-ENC-001/002/003 | Gap **G-06** | Requires the encryption layer. |
| SEC-TEST-ISO-001/002 | Gap **G-06** | Requires the session layer. |
| SEC-TEST-REPLAY-001 | Gap **G-06** | Requires the message layer. |
| SEC-TEST-MEDIA-001 | Partially satisfied | Pre-operation removal detection is implemented and testable by removing the card and running `sd read`. Mid-operation abort is **G-02**. |

## §11 Requirements Traceability

| ID | Disposition | Evidence / rationale |
| --- | --- | --- |
| §11 | Satisfied | Every firmware source and header carries an `EZ-SEC-001 traceability` block naming the requirement IDs it satisfies, supports, or is exempt from. This matrix names evidence for every satisfied row. |

---

## Code Review Record (SEC-FW-001)

A manual memory-safety and correctness review of all 3,100 lines of C was
performed for this audit. Bounds on every array write were traced to their
clamping site. Three defects were found by review and two more on hardware:

**Finding 1 — stale capture length after buffer reuse (correctness, security-relevant).**
The 192 KB capture buffer doubled as scratch for the FRAM and SD tests at nine
call sites, none of which reset `g_payload_len`. Running `fram bench` after
`hrng cap` left the length claiming a capture that had been overwritten with
test patterns; `send` would then transmit that scratch data under a valid
CRC-32 and correct-looking metadata, and the host would analyse FRAM test
patterns as if they were entropy. Fixed by `buffer_take_scratch()`, which
zeroises and invalidates. This also brings the artifact into compliance with
SEC-FW-003.

**Finding 2 — FRAM addressing mode left corrupted after failed detection.**
`ez_fram_detect_size()` sets the global address width to 2 then 3 while
probing. On a device that failed both probes it returned with the width left at
3, so every subsequent read and write on a 2-byte-addressed part silently
targeted the wrong address. Fixed by restoring the previous width on failure.

**Finding 3 — negative argument count passed to a parser.**
`hrng restart` with no arguments computed `argc - 3 = -1` and passed it with
`argv + 3`. The loop guard made it harmless in practice, but the pointer
arithmetic and the negative count were both unsound. Clamped at all three call
sites.

**Also found during this audit, in the metadata path:** adding the
non-key-material tag pushed the JSON metadata past the 488-byte header budget.
`snprintf` would have truncated it silently, producing invalid JSON that the
host rejects only *after* a capture costing minutes to hours. The header is now
1024 bytes, truncation is detected and reported, and the host reads `header_len`
from the container so captures from either firmware revision parse.

**Finding 4 — pin test destroyed the SPI pin functions (found on hardware).**
`ez_pins_check()` calls `gpio_init()` on every board pin, which switches it to
SIO. It never restored the previous function, so GPIO18-21 were left as plain
inputs and every subsequent FRAM transfer read 0x00 — indistinguishable from a
dead part. `selftest` runs the pin check before the FRAM check, so it hit this
too. Fixed by saving and restoring function, direction and output level per
pin. Firmware 1.1.1.

**Finding 5 — FRAM presence was inferred from RDID alone.**
`fram id` treated an all-zero response to opcode 0x9F as a dead bus. RDID is
not universal: the original Fujitsu MB85RS64 family has no Device ID command,
so a healthy part reports all zeroes. Replaced with `ez_fram_probe()`, which
toggles the write-enable latch via WREN/WRDI and reads it back through RDSR --
supported by every SPI FRAM, non-destructive, and conclusive in both bus
directions. Firmware 1.1.1.

**Finding 4 — pin test destroyed the SPI bus configuration (found on hardware).**
`ez_pins_check()` calls `gpio_init()` on GPIO18-21 and GPIO26-29 to drive the
internal pulls, which switches each pin to SIO and tears down its SPI function.
It never restored them. Any FRAM or SD command run after `pins` — including
everything in `selftest`, which runs the pin test first — therefore talked to
disconnected pins, and every read returned 0x00. This presented as a dead FRAM
on hardware that was working correctly. Fixed by saving `gpio_get_function()`,
direction and output level per pin and restoring them after the probe.

**Finding 5 — presence was inferred from an optional command (found on hardware).**
`fram id` treated an all-zero RDID response as "dead bus". Not every SPI FRAM
implements RDID (0x9F): the Fujitsu MB85RS64 family, which is the part on
Blaustahl, has no Device ID command at all. Presence is now established by the
WREN/WRDI write-enable-latch toggle, which every SPI FRAM supports and which is
non-destructive. Absence of RDID is reported as a property of the part.

**Not covered:** no static analysis, no sanitizer build, no fuzzing of the
XMODEM or CLI parsers. Both parsers consume untrusted-ish input from the host
link. Recorded as **G-03**.

---

## Verification performed for this audit

| Check | Result |
| --- | --- |
| Firmware builds, default configuration | clean, 0 warnings under `-Wall -Wextra` |
| Bench findings 4 and 5 fixed and rebuilt | clean |
| Firmware builds, `-DEZ_ENABLE_RAW_STORAGE_DUMP=ON` | clean, CMake emits the required warning |
| Host analysis self-test, 4 sources of known entropy | pass, no estimator overstates |
| AIS-31 on uniform data | all 9 tests pass |
| FIPS 140-2 §4.9.1 on uniform data | 160/160 blocks pass all four tests |
| SP 800-22 on uniform data | 13 ran, 13 pass (2 skipped for insufficient excursion cycles) |
| SP 800-22 on 2% biased data | 10 of 13 fail, as expected |
| Container round-trip, both header revisions | pass, XMODEM padding trimmed correctly |

Firmware footprint: 71,872 B text, 202,848 B BSS on a 520 KB part.

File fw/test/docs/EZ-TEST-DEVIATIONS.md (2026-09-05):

# EZ-SEC-001 Deviations and Gaps — Test Firmware

**Artifact:** `fw/test/`
**Document ID:** EZ-TEST-DEV-001
**Governing spec:** EZ-SEC-001
**Status:** Open items. Companion to `EZ-TEST-TRACEABILITY.md`.

Two classes of item are recorded here.

**Deviations (D-nn)** are places where this artifact knowingly does not comply
and where compliance would defeat its purpose. Each is justified, mitigated,
and bounded. They are not scheduled for remediation; they are scheduled for
*containment* — the containment measure is named in each entry.

**Gaps (G-nn)** are places where compliance is intended but not yet achieved.
Each has an owner-facing action.

The one-line summary: **this artifact must never be flashed to a device that
holds key material, and must never be present in a build that generates it.**
Every deviation below is safe only under that condition, and `ez_guard.c`
enforces the first half of it in software.

---

## Deviations

### D-01 — Optional raw storage read paths violate SEC-FW-004 and SEC-UI-005

**Requirement:** SEC-FW-004 ("MUST NOT expose a command, interface, or debug
path that allows raw read access to key data storage"), SEC-UI-005 (OTP offsets
must not appear in diagnostic output).

**Deviation:** `fram dump` and the block hexdump in `sd read` are raw read paths
into metadata storage and key data storage respectively. On V1 the microSD *is*
key data storage, so hexdumping an arbitrary LBA is precisely what SEC-FW-004
prohibits.

**Why it exists:** bringing up an SPI bus without being able to see the bytes on
it is considerably harder. The capability has genuine diagnostic value on a bare
board.

**Containment:**
- Both paths are compiled out by default (`EZ_ENABLE_RAW_STORAGE_DUMP=OFF`).
- In the default build, `fram dump` returns rc=3 and cites this requirement.
- In the default build, `sd read` still performs the read and verifies the
  card's data CRC-16 — which is what the bus integrity test actually needs —
  and withholds only the contents.
- When the option is enabled, CMake emits a warning naming both requirement IDs,
  and the paths remain gated on `ez_guard_permit_storage()`.

**Residual risk:** a binary built with the option ON is non-compliant and
indistinguishable from a compliant one at a glance. **Action:** if this
concerns you, remove the option entirely and keep a private branch for bring-up.

---

### D-02 — Raw capture mode disables hardware debiasing (SEC-ENTROPY-003)

**Requirement:** SEC-ENTROPY-003 — TRNG output must not be conditioned in a way
that introduces determinism; hardware debiasing must not reduce per-byte entropy
below 8 bits.

**Deviation:** raw mode sets `VNC_BYPASS`, `TRNG_CRNGT_BYPASS` and
`AUTO_CORRELATE_BYPASS`, producing output that will be well below 8 bits per
byte.

**Why it exists:** SP 800-90B assesses the *noise source*, not the conditioned
output. Assessing post-conditioning data measures the conditioner. This is the
same reasoning the project README already gives for deprecating V0's ATSHA204A
DRBG output.

**Containment:** raw captures are tagged `"key_material": false`, the report
prints a banner saying so, and conditioned mode (health tests enabled) is
captured alongside for comparison.

**Note for the spec, not for this artifact:** SEC-ENTROPY-003's second sentence
is worth revisiting. The Von Neumann balancer *is* hardware debiasing, and its
purpose is to *raise* entropy density, not preserve it. As written the sentence
reads as though debiasing is a risk to be bounded; in practice V1's ability to
meet SEC-ENTROPY-002 will depend on it. Consider rewording to require that
post-debiasing output achieve 8 bits/byte, with the raw-source min-entropy
documented separately.

---

### D-03 — The tool continues past TRNG health-test faults (SEC-ENTROPY-004)

**Requirement:** SEC-ENTROPY-004 — generation must halt and raise an auditable
fault if the entropy source is degraded.

**Deviation:** `ez_trng_capture()` records CRNGT, Von Neumann and autocorrelation
faults, recovers from the fatal autocorrelation case with a software reset, and
keeps going.

**Why it exists:** a fail-safe source cannot be characterised, because the
failure being characterised is the thing that stops the run. The fault *rate* is
itself a measurement.

**Containment:** every fault count is carried in the capture metadata and
rendered in the report. Conditioned mode leaves all three tests enabled, so the
production configuration can be observed behaving correctly.

**Action for production firmware:** SEC-ENTROPY-004 requires an auditable fault.
This artifact demonstrates that the fault bits are readable and that the
autocorrelation fault is genuinely fatal in hardware ("RNG cease from
functioning until next reset"), which production firmware must handle rather
than hang on.

---

### D-04 — Bulk buffering of TRNG output (SEC-GEN-001)

**Requirement:** SEC-GEN-001 — key bytes must not be buffered in volatile memory
longer than needed to write a single block.

**Deviation:** up to 192 KB of TRNG output is held in RAM for the duration of a
capture and a transfer.

**Why it exists:** entropy assessment needs contiguous samples; SP 800-90B wants
at least 10⁶.

**Containment:** the data is not key material. `ez_secure_zero()` clears the
buffer at every role change and `buf zero` performs a verified wipe on demand.

---

### D-05 — Entropy leaves the device electronically (SEC-DIST-001)

**Requirement:** SEC-DIST-001 — electronic transmission of key material over any
network is prohibited.

**Deviation:** captures are transferred over USB CDC to a host for analysis.

**Why it exists:** the analysis cannot run on the device.

**Containment:** the transferred bytes are never used as key material, are tagged
as such in the container metadata, and the generated report carries a warning
banner. The USB link is point-to-point, not a network.

**Residual risk:** the tagging is advisory. Nothing physically prevents someone
piping a `.bin` into a key slot. **Action:** if V1 firmware ever gains a key
import path, it must reject files carrying `"key_material": false` and must not
accept key material over USB at all.

---

## Gaps
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

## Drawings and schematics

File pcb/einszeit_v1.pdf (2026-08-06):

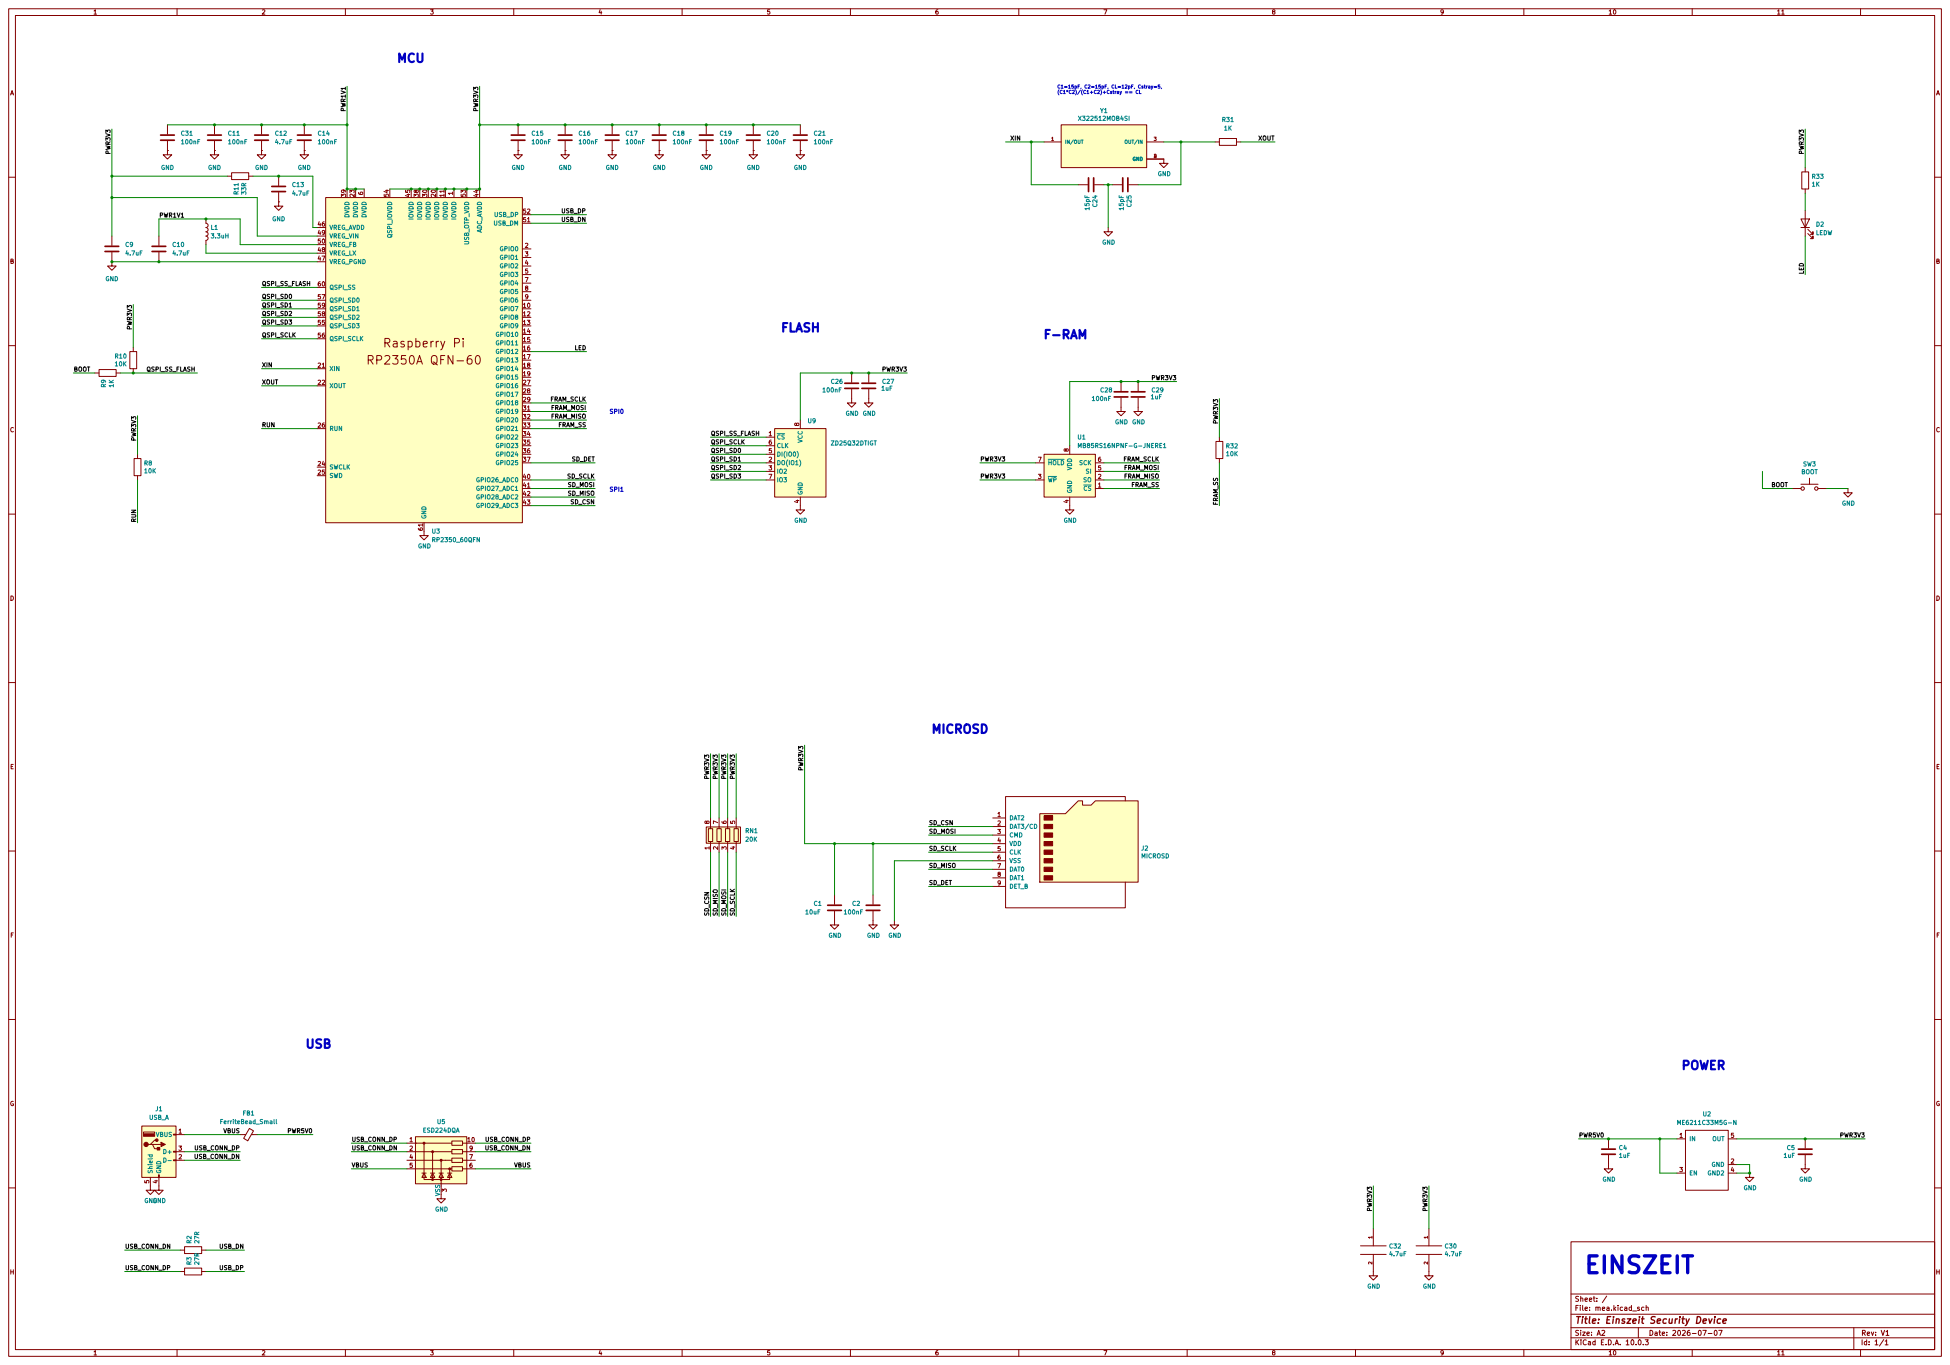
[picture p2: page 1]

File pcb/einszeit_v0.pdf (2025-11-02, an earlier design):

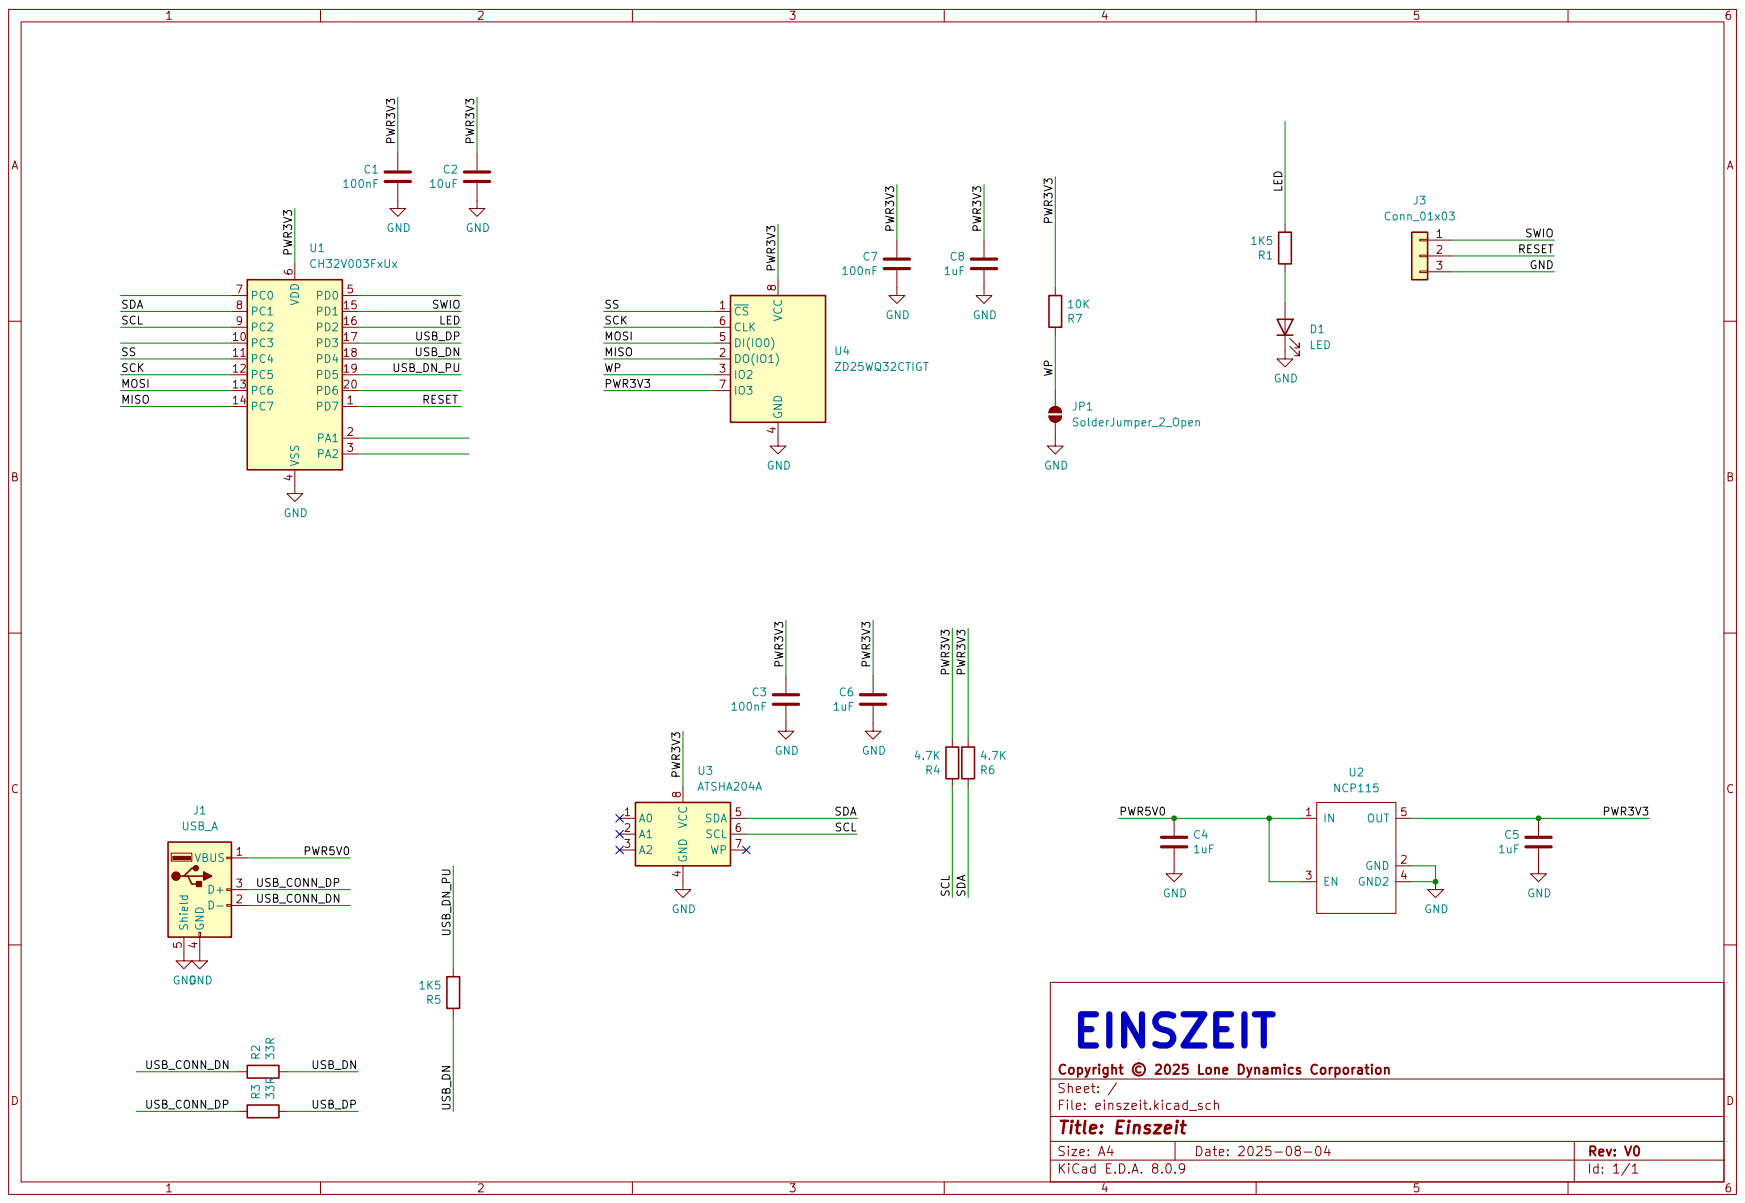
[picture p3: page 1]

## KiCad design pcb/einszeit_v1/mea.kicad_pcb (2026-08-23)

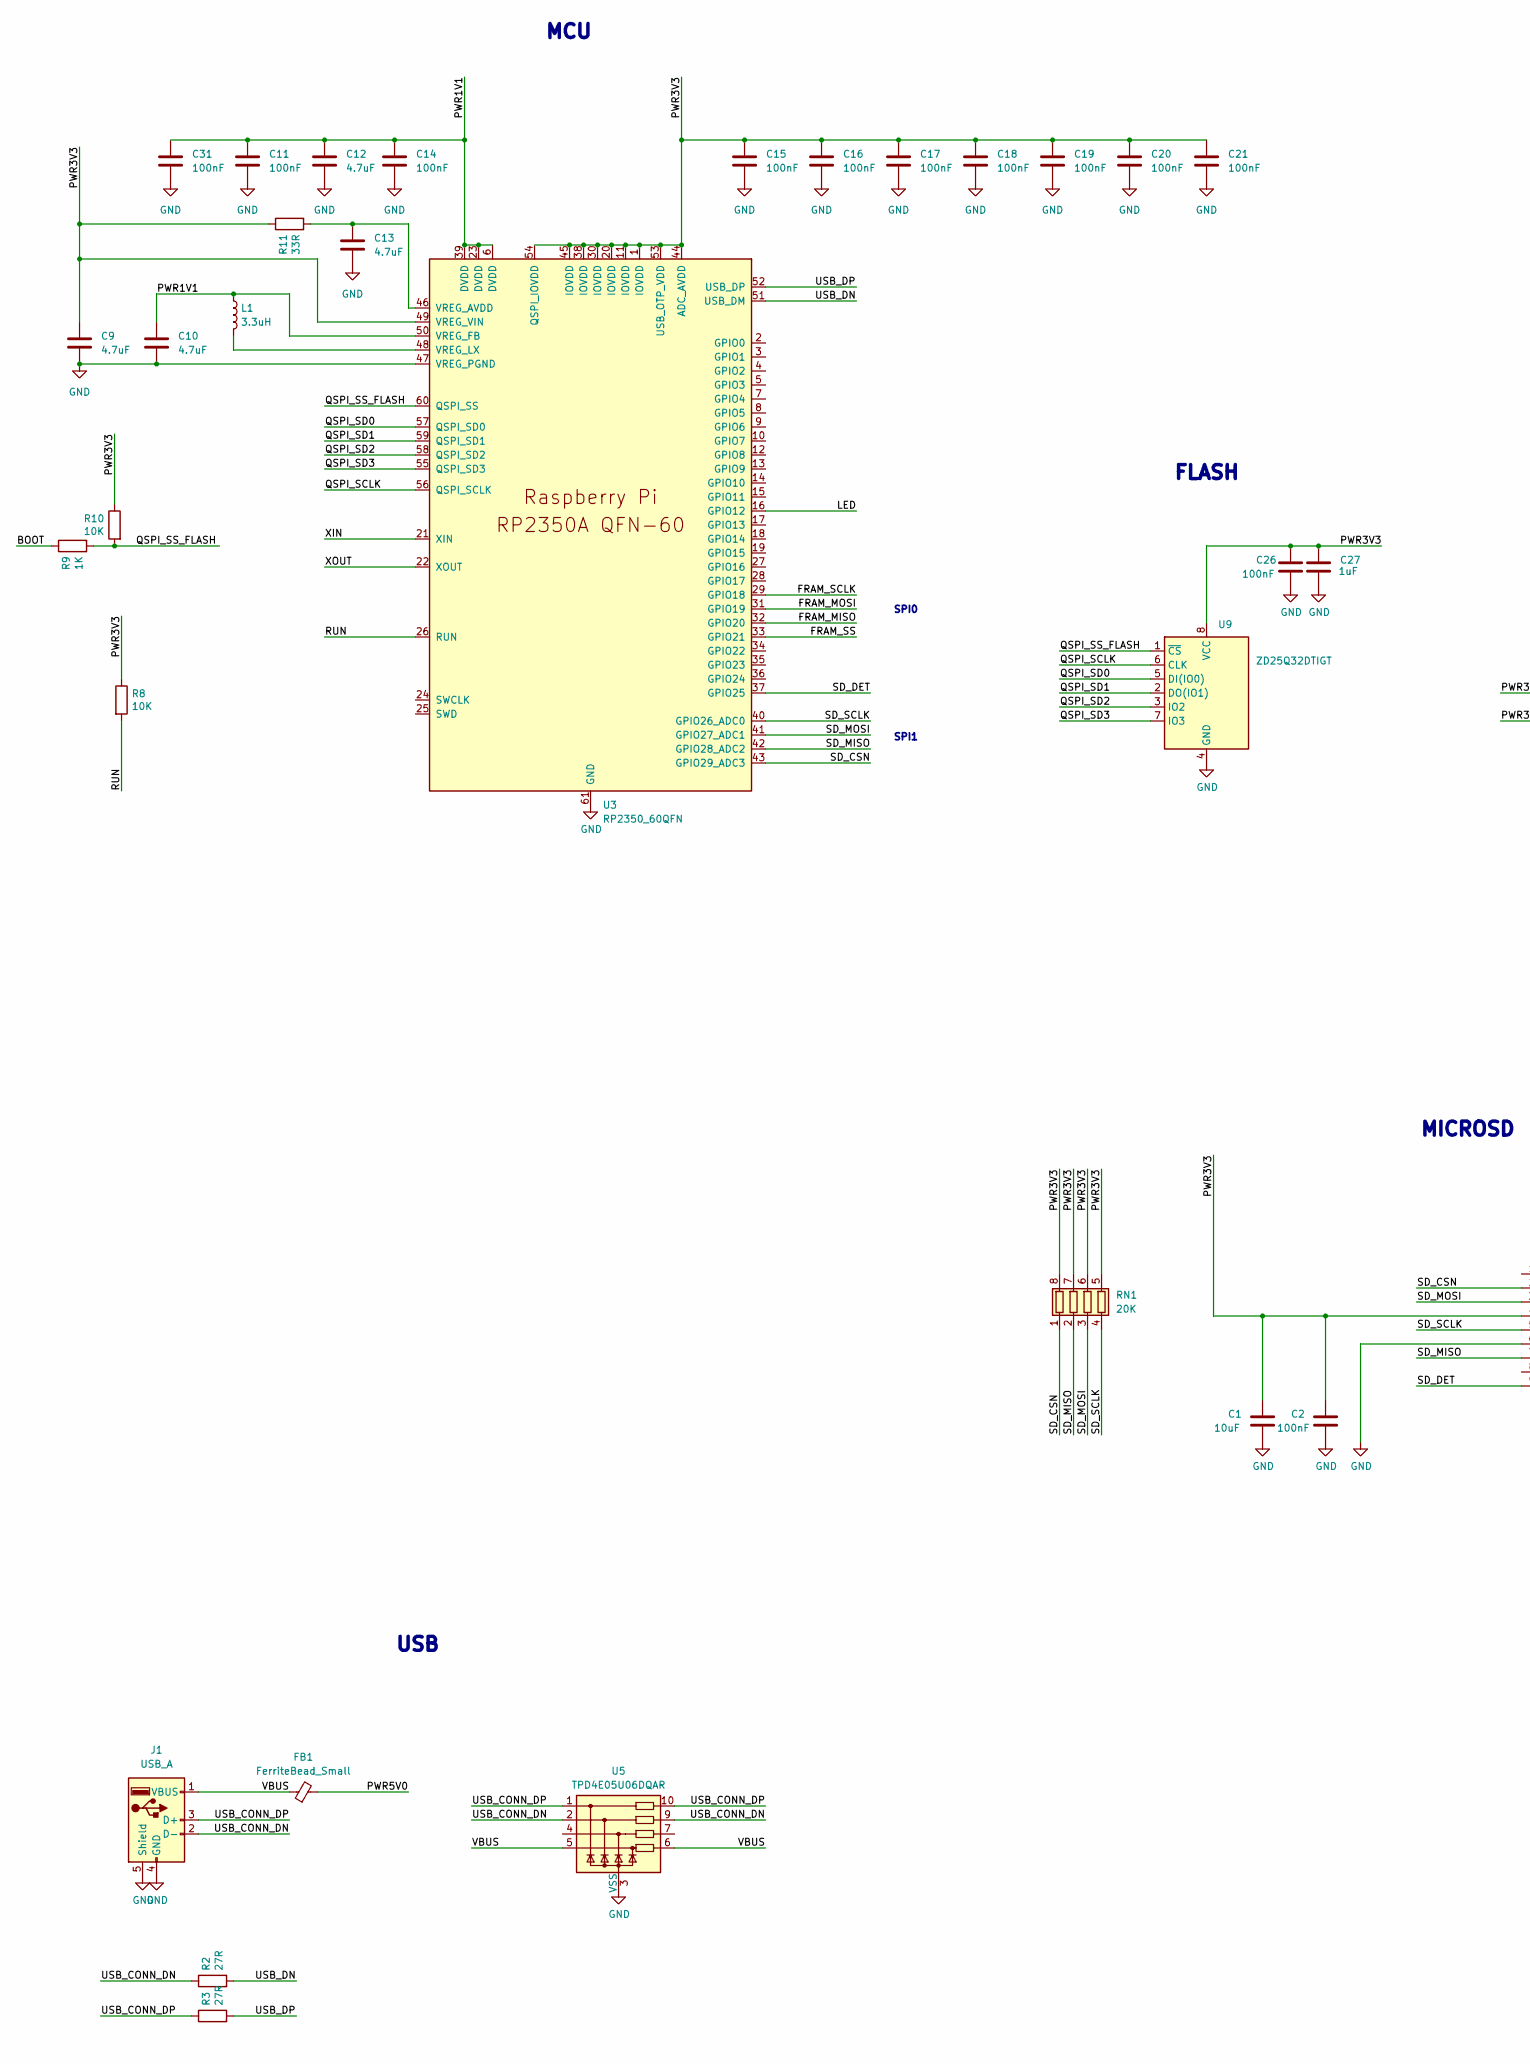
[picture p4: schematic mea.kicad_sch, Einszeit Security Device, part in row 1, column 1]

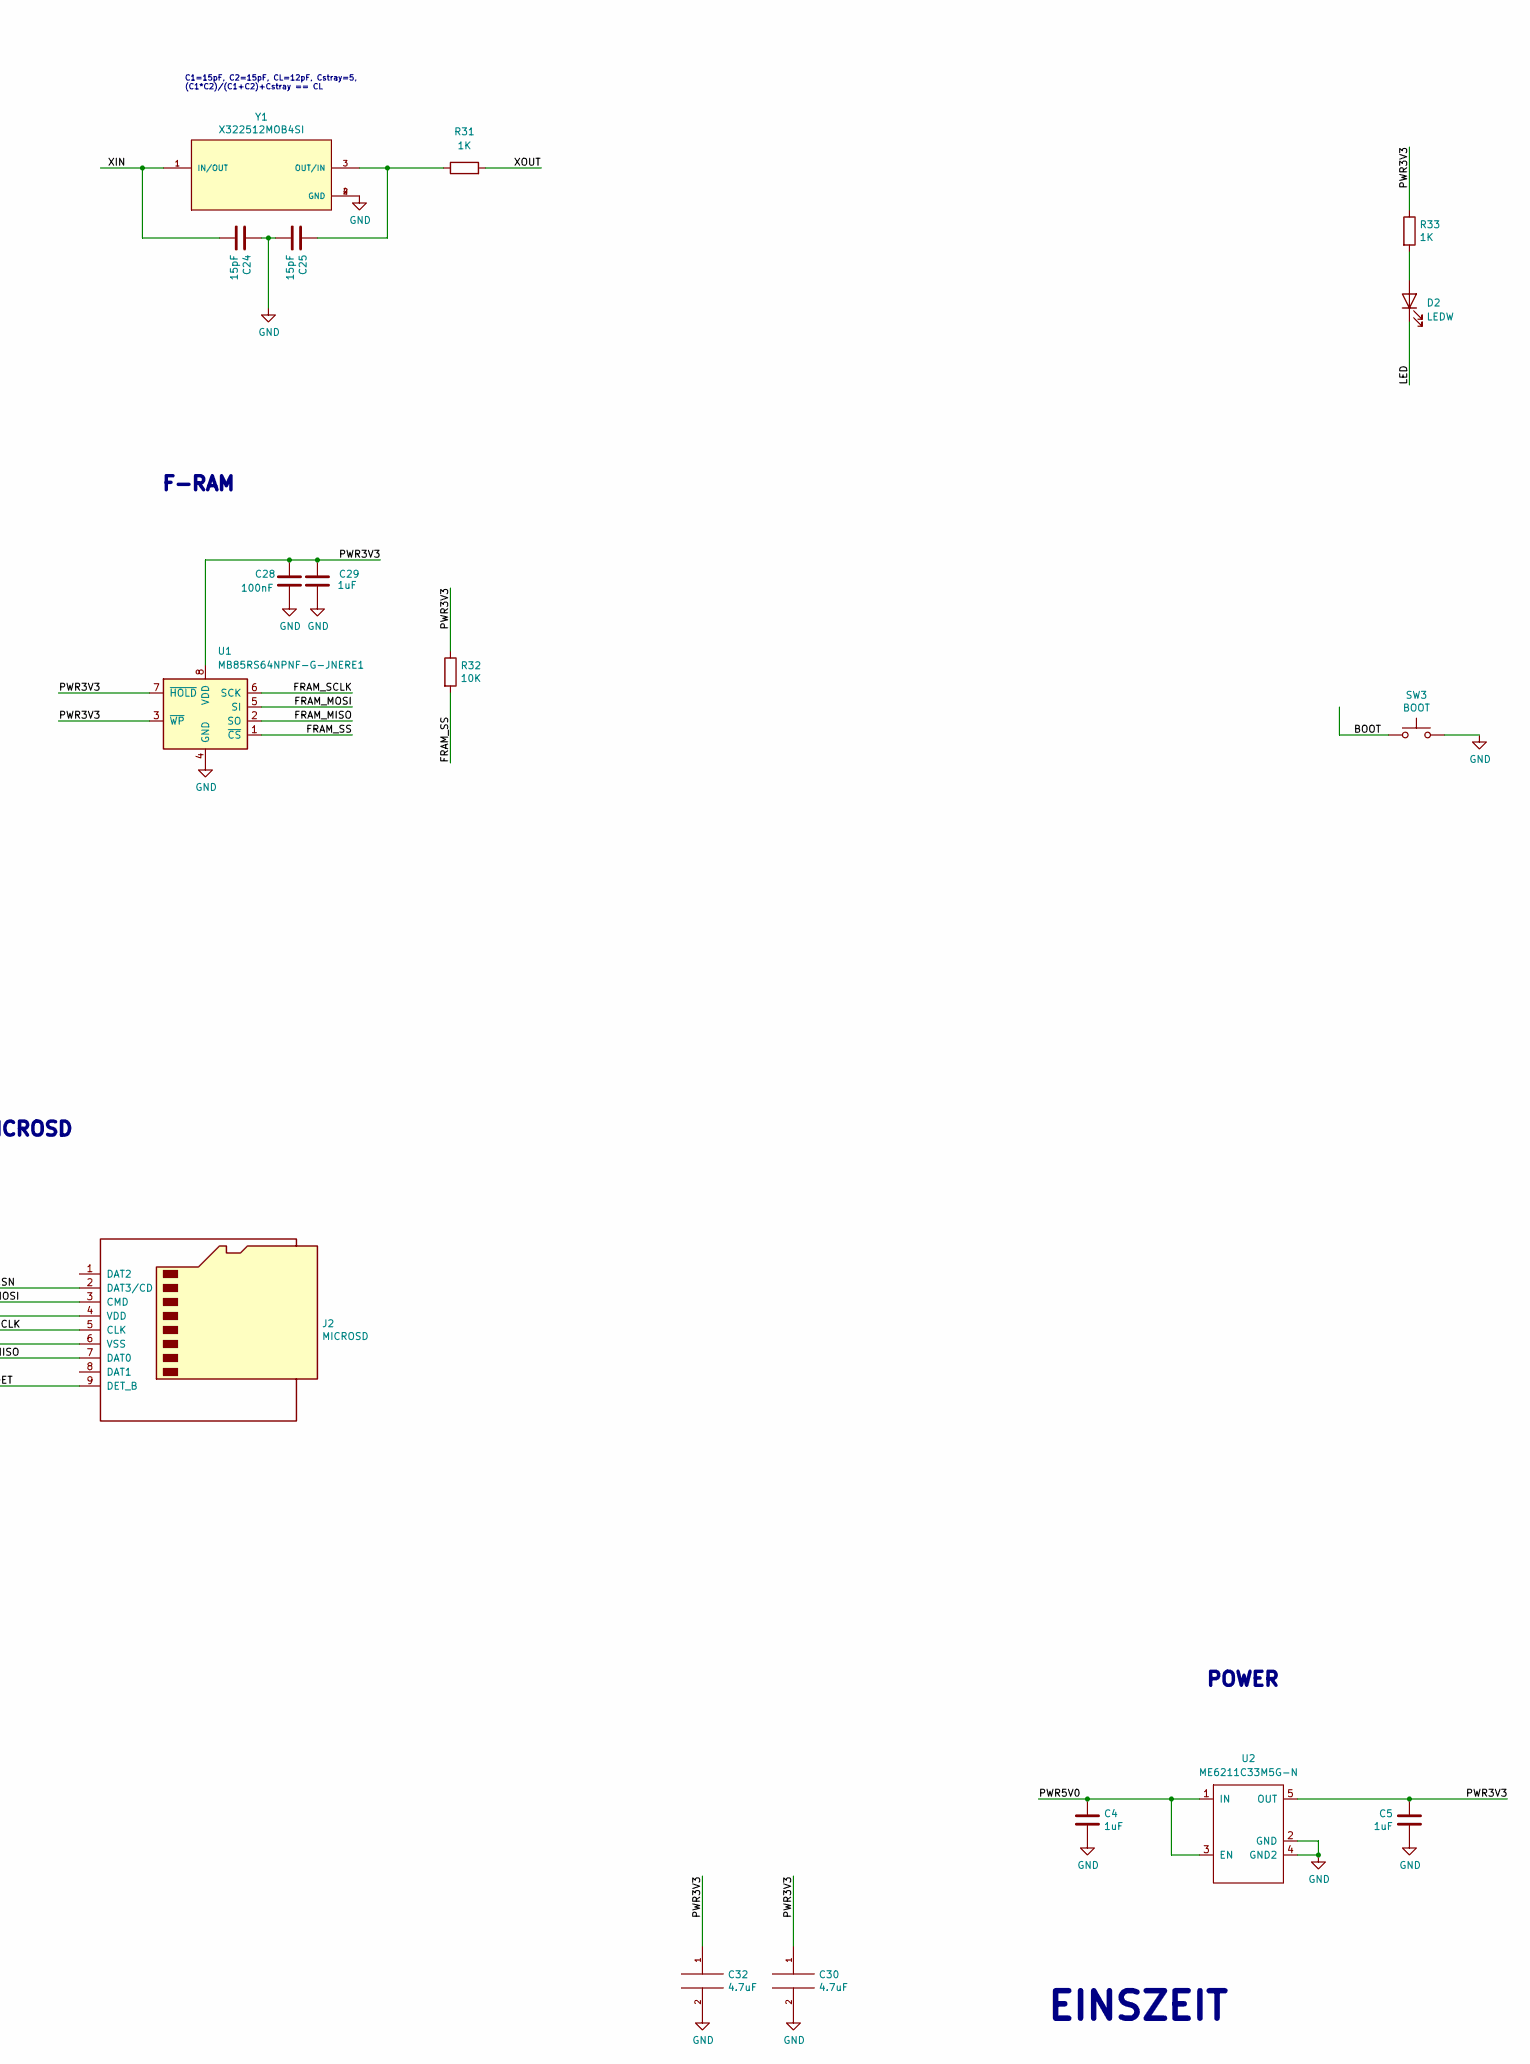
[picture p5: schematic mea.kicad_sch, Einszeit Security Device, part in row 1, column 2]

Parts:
C1: 10uF; C_0402_1005Metric
C2, C11, C14, C15, C16, C17, C18, C19, C20, C21, C26, C28, C31: 100nF; C_0402_1005Metric
C4, C5, C27, C29: 1uF; C_0402_1005Metric
C9, C10, C12, C13, C30, C32: 4.7uF; C_0402_1005Metric
C24, C25: 15pF; C_0402_1005Metric
D2: LEDW; LED_0603_1608Metric
FB1: FerriteBead_Small; R_0402_1005Metric
J1: USB_A; USB_A_CNCTech_1001-011-01101_Horizontal
J2: MICROSD; TF-018B-H15-HAND-SOLDER
L1: 3.3uH; L_Murata_DFE201610P
R2, R3: 27R; R_0402_1005Metric
R8, R10, R32: 10K; R_0402_1005Metric
R9, R31, R33: 1K; R_0402_1005Metric
R11: 33R; R_0402_1005Metric
RN1: 20K; R_Array_Convex_4x0402
SW3: BOOT; Button_2P_3x4mm
U1: MB85RS64NPNF-G-JNERE1; SOIC-8_3.9x4.9mm_P1.27mm
U2: ME6211C33M5G-N; TSOP-5_1.65x3.05mm_P0.95mm
U3: RP2350_60QFN; RP2350-QFN-60-1EP_7x7_P0.4mm_EP3.4x3.4mm_ThermalVias
U5: TPD4E05U06DQAR; Diodes_UDFN-10_1.0x2.5mm_P0.5mm
U9: ZD25Q32DTIGT; SOIC-8_3.9x4.9mm_P1.27mm
Y1: X322512MOB4SI; XTAL_ECS-240-8-33-AGN-TR

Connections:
/BOOT: R9.1, SW3.1
/FRAM_MISO: U1.2 (SO), U3.32 (GPIO20)
/FRAM_MOSI: U1.5 (SI), U3.31 (GPIO19)
/FRAM_SCLK: U1.6 (SCK), U3.29 (GPIO18)
/FRAM_SS: R32.2, U1.1 (~CS), U3.33 (GPIO21)
/LED: D2.1 (K), U3.16 (GPIO12)
/PWR1V1: C10.1, C11.1, C12.1, C14.1, C31.1, L1.1, U3.6 (DVDD), U3.23 (DVDD), U3.39 (DVDD), U3.50 (VREG_FB)
/PWR3V3: C1.1, C2.1, C5.1, C9.1, C15.1, C16.1, C17.1, C18.1, C19.1, C20.1, C21.1, C26.1, C27.1, C28.1, C29.1, C30.1, C32.1, J2.4 (VDD), R8.1, R10.1, R11.1, R32.1, R33.1, RN1.5 (R4.2), RN1.6 (R3.2), RN1.7 (R2.2), RN1.8 (R1.2), U1.3 (~WP), U1.7 (~HOLD), U1.8 (VDD), U2.5 (OUT), U3.1 (IOVDD), U3.11 (IOVDD), U3.20 (IOVDD), U3.30 (IOVDD), U3.38 (IOVDD), U3.44 (ADC_AVDD), U3.45 (IOVDD), U3.49 (VREG_VIN), U3.53 (USB_OTP_VDD), U3.54 (QSPI_IOVDD), U9.8 (VCC)
/PWR5V0: C4.1, FB1.2, U2.1 (IN), U2.3 (EN)
/QSPI_SCLK: U3.56 (QSPI_SCLK), U9.6 (CLK)
/QSPI_SD0: U3.57 (QSPI_SD0), U9.5 (DI(IO0))
/QSPI_SD1: U3.59 (QSPI_SD1), U9.2 (DO(IO1))
/QSPI_SD2: U3.58 (QSPI_SD2), U9.3 (IO2)
/QSPI_SD3: U3.55 (QSPI_SD3), U9.7 (IO3)
/QSPI_SS_FLASH: R9.2, R10.2, U3.60 (QSPI_SS), U9.1 (~CS)
/RUN: R8.2, U3.26 (RUN)
/SD_CSN: J2.2 (DAT3/CD), RN1.1 (R1.1), U3.43 (GPIO29_ADC3)
/SD_DET: J2.9 (DET_B), U3.37 (GPIO25)
/SD_MISO: J2.7 (DAT0), RN1.2 (R2.1), U3.42 (GPIO28_ADC2)
/SD_MOSI: J2.3 (CMD), RN1.3 (R3.1), U3.41 (GPIO27_ADC1)
/SD_SCLK: J2.5 (CLK), RN1.4 (R4.1), U3.40 (GPIO26_ADC0)
/USB_CONN_DN: J1.2 (D-), R2.1, U5.2, U5.9
/USB_CONN_DP: J1.3 (D+), R3.1, U5.1, U5.10
/USB_DN: R2.2, U3.51 (USB_DM)
/USB_DP: R3.2, U3.52 (USB_DP)
/VBUS: FB1.1, J1.1 (VBUS), U5.5, U5.6
/XIN: C24.2, U3.21 (XIN), Y1.1 (IN/OUT)
/XOUT: R31.2, U3.22 (XOUT)
GND: C1.2, C2.2, C4.2, C5.2, C9.2, C10.2, C11.2, C12.2, C13.2, C14.2, C15.2, C16.2, C17.2, C18.2, C19.2, C20.2, C21.2, C24.1, C25.2, C26.2, C27.2, C28.2, C29.2, C30.2, C31.2, C32.2, J1.4 (GND), J1.5 (Shield), J2.6 (VSS), SW3.2, U1.4 (GND), U2.2 (GND), U2.4 (GND2), U3.47 (VREG_PGND), U3.61 (GND), U5.3 (VSS), U5.8 (VSS), U9.4 (GND), Y1.2 (GND), Y1.4 (GND)
unnamed: D2.2 (A), R33.2
unnamed: C13.1, R11.2, U3.46 (VREG_AVDD)
unnamed: L1.2, U3.48 (VREG_LX)
unnamed: C25.1, R31.1, Y1.3 (OUT/IN)

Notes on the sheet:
F-RAM
POWER
MICROSD
C1=15pF, C2=15pF, CL=12pF, Cstray=5, (C1*C2)/(C1+C2)+Cstray == CL
MCU
SPI0
FLASH
EINSZEIT
SPI1
USB

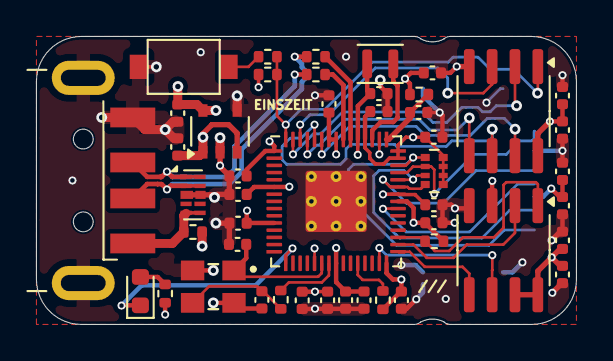
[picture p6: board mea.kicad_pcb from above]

Board: 4 copper layers, 30.0 x 16.0 mm, 48 parts (1 on the bottom side), 33 nets.

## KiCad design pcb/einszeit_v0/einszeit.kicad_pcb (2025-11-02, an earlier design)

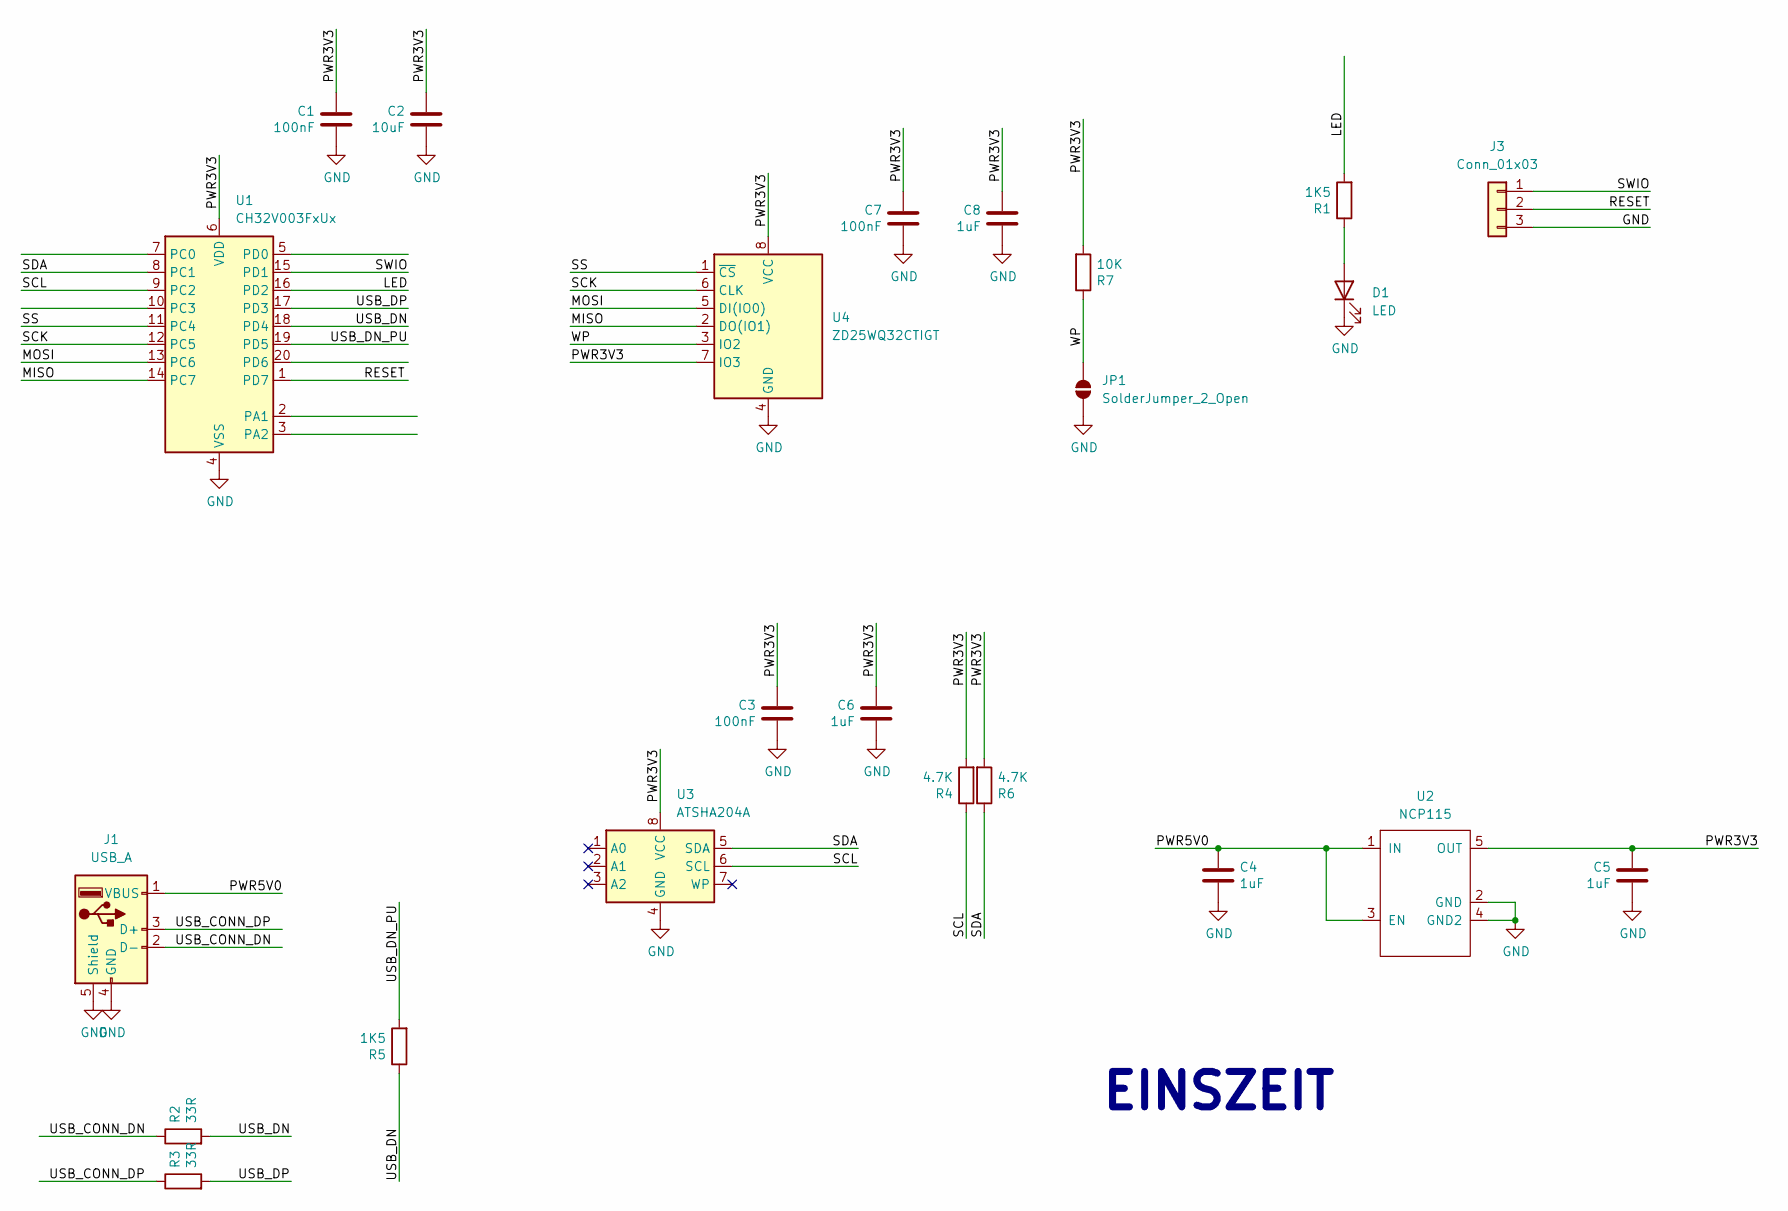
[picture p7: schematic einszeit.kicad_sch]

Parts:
C1, C3, C7: 100nF; C_0402_1005Metric
C2: 10uF; C_0402_1005Metric
C4, C5, C6, C8: 1uF; C_0402_1005Metric
D1: LED; LED_0603_1608Metric
J1: USB_A; USB_A_CNCTech_1001-011-01101_Horizontal
J3: Conn_01x03; PinHeader_1x03_P2.54mm_Vertical
JP1: SolderJumper_2_Open; SolderJumper-2_P1.3mm_Open_Pad1.0x1.5mm
R1, R5: 1K5; R_0402_1005Metric
R2, R3: 33R; R_0402_1005Metric
R4, R6: 4.7K; R_0402_1005Metric
R7: 10K; R_0402_1005Metric
U1: CH32V003FxUx; QFN-20-1EP_3x3mm_P0.4mm_EP1.65x1.65mm
U2: NCP115; TSOP-5_1.65x3.05mm_P0.95mm
U3: ATSHA204A; SOIC-8_3.9x4.9mm_P1.27mm
U4: ZD25WQ32CTIGT; SOP-8_3.9x4.9mm_P1.27mm

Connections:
/LED: R1.2, U1.16 (PD2)
/MISO: U1.14 (PC7), U4.2 (DO(IO1))
/MOSI: U1.13 (PC6), U4.5 (DI(IO0))
/PWR3V3: C1.1, C2.1, C3.1, C5.1, C6.1, C7.1, C8.1, R4.2, R6.2, R7.2, U1.6 (VDD), U2.5 (OUT), U3.8 (VCC), U4.7 (IO3), U4.8 (VCC)
/PWR5V0: C4.1, J1.1 (VBUS), U2.1 (IN), U2.3 (EN)
/RESET: J3.2, U1.1 (PD7)
/SCK: U1.12 (PC5), U4.6 (CLK)
/SCL: R4.1, U1.9 (PC2), U3.6 (SCL)
/SDA: R6.1, U1.8 (PC1), U3.5 (SDA)
/SS: U1.11 (PC4), U4.1 (~CS)
/SWIO: J3.1, U1.15 (PD1)
/USB_CONN_DN: J1.2 (D-), R2.1
/USB_CONN_DP: J1.3 (D+), R3.1
/USB_DN: R2.2, R5.1, U1.18 (PD4)
/USB_DN_PU: R5.2, U1.19 (PD5)
/USB_DP: R3.2, U1.17 (PD3)
/WP: JP1.2 (B), R7.1, U4.3 (IO2)
GND: C1.2, C2.2, C3.2, C4.2, C5.2, C6.2, C7.2, C8.2, D1.1 (K), J1.4 (GND), J1.5 (Shield), J3.3, JP1.1 (A), U1.4 (VSS), U1.21 (VSS), U2.2 (GND), U2.4 (GND2), U3.4 (GND), U4.4 (GND)
unnamed: D1.2 (A), R1.1

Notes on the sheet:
EINSZEIT

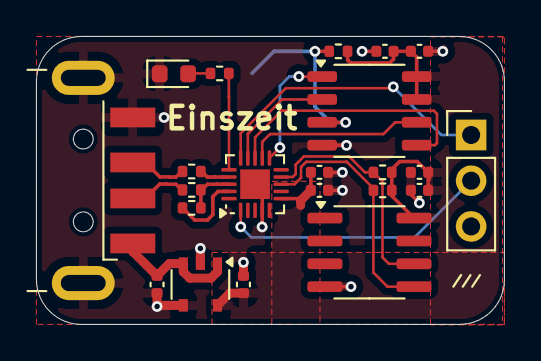
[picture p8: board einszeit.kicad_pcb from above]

Board: 2 copper layers, 26.0 x 16.0 mm, 23 parts (1 on the bottom side), 19 nets.

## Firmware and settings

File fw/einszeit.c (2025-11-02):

/*
 * Einszeit Firmware
 *
 * Copyright (c) 2023 CNLohr
 * Copyright (c) 2025 Lone Dynamics Corporation. All rights reserved.
 *
 */

#include <stdio.h>
#include <string.h>
#include <stdint.h>
#include <stdbool.h>
#include "rv003usb.h"
#include "ch32fun.h"

#define EZ_KEY_LEN (1024 * 1024 * 4)

#define CH32V003_SPI_IMPLEMENTATION
#define CH32V003_SPI_NSS_SOFTWARE_ANY_MANUAL
#define CH32V003_SPI_SPEED_HZ 1000000
#define CH32V003_SPI_DIRECTION_2LINE_TXRX
#define CH32V003_SPI_CLK_MODE_POL0_PHA0

#define I2C_DELAY_US 1  // 5us delay = ~100kHz I2C
//#define I2C_DELAY_US 5  // 5us delay = ~100kHz I2C

#define ATSHA_ZONE_DATA       0x02  // Data zone (vs Config=0x00 or OTP=0x01)
#define ATSHA_SLOT_SIZE       32    // Size in bytes of each data slot
#define ATSHA_SLOT_COUNT      4     // Number of data slots available
                                    // (ideally this would be 16)

#include "ch32fun/extralibs/ch32v003_SPI.h"

#define ATSHA204A_I2C_ADDR  0x64

#define I2C_SDA	1
#define I2C_SCL	2
#define SPI_SS		4
#define LED			2

#define EZ_CMD_PING 0x00
#define EZ_CMD_STATUS 0x01
#define EZ_CMD_IDENTIFY 0x10
#define EZ_CMD_KEY_GEN 0x11
#define EZ_CMD_COPY 0x20
#define EZ_CMD_ERASE 0x50

#define EZ_CMD_META_LOAD 0x60

#define EZ_CMD_RAND 0x80

#define EZ_CMD_ENCRYPT 0xa0
#define EZ_CMD_DECRYPT 0xb0
#define EZ_CMD_DECRYPT_SELF 0xb1
#define EZ_CMD_INC 0xc0

#define EZ_CMD_DUMP_CONFIG 0xd0
#define EZ_CMD_LOCK 0xf0

void i2c_scan(void);
void i2c_init(uint32_t pclk_mhz, uint32_t speed_hz);
int i2c_write(uint8_t addr, const uint8_t *data, uint8_t len);
int i2c_read(uint8_t addr, uint8_t *data, uint8_t len);
static uint16_t atsha_crc(const uint8_t *data, uint8_t len);
void atsha204a_wake(void);
int atsha204a_get_random(uint8_t *out32);

int atsha204a_dump_config(void);
int atsha204a_factory_lock(void);
int atsha204a_lock(uint8_t zone);

int atsha204a_load_eeprom(uint8_t *out, uint8_t slot_id);
int atsha204a_save_eeprom(const uint8_t *data, uint8_t slot_id);

void flash_read(uint8_t *buf, uint32_t addr, uint32_t size);
void flash_write(const uint8_t *buf, uint32_t addr, uint32_t size);
void flash_erase(void);
int32_t flash_read_id(void);

void ez_generate_keys(void);
int ez_identity(void);
int ez_identify(uint8_t id);
uint32_t ez_send_ptr(void);

int ez_update_meta(uint32_t send_ptr_inc, bool boot_ctr_inc);
int ez_find_current_metadata(uint8_t *out_meta);

#pragma pack(1)
typedef struct ez_meta {

   uint16_t magic;
   uint32_t seq;
   uint32_t send_ptr;
   uint32_t boot_ctr;
   uint8_t id;
   uint8_t reserved[16];
   uint8_t crc;

} ez_meta_t;

// Allow reading and writing to the scratchpad via HID control messages.
uint8_t scratch[255];

volatile uint8_t start = 0;

uint8_t do_key_gen = 0;
uint32_t key_gen;
uint32_t key_len = EZ_KEY_LEN;

int main()
{
	SystemInit();

	Delay_Ms(1); // Ensures USB re-enumeration after bootloader or reset; Spec demand >2.5µs ( TDDIS )
	usb_setup();

	GPIOD->CFGLR &= ~(0xf<<(4*LED));
	GPIOD->CFGLR |= (GPIO_Speed_10MHz | GPIO_CNF_OUT_PP)<<(4*LED);

	i2c_init(48, 100000);
	Delay_Ms(1);

	SPI_init();
	SPI_begin_8();
	Delay_Ms(1);

   uint32_t flash_id = flash_read_id();
   printf("Flash ID: 0x%06X\r\n", flash_id);

	GPIOC->CFGLR &= ~(0xf<<(4*SPI_SS));
	GPIOC->CFGLR |= (GPIO_Speed_50MHz | GPIO_CNF_OUT_PP)<<(4*SPI_SS);
	GPIOC->BSHR = (1<<(16+SPI_SS));

	// main loop

	while(1)
	{
#if RV003USB_EVENT_DEBUGGING	// doesn't work without this?
      uint32_t * ue = GetUEvent();
      if( ue )
      {
         printf( "%lu %lx %lx %lx\n", ue[0], ue[1], ue[2], ue[3] );
      }
#endif

		if (start && scratch[0] == 0xaa && scratch[1] == 0x00) {

			// scratch formats:
			// 0xaa 0x00 <cmd> <arg> <arg> <arg>
			// response:
			// 0xaa 0x01 <response data>

			// LED on
			GPIOD->BSHR = (1<<LED);

			if (scratch[2] == EZ_CMD_PING) {

				scratch[2] = 0x99;
				scratch[3] = 0x89;
				scratch[4] = 0x79;
				scratch[5] = 0x69;

			}

			if (scratch[2] == EZ_CMD_STATUS) {

				scratch[2] = 0x01;
				scratch[3] = (key_gen >> 24) & 0xff;
				scratch[4] = (key_gen >> 16) & 0xff;
				scratch[5] = (key_gen >> 8) & 0xff;
				scratch[6] = key_gen & 0xff;

			}

			if (scratch[2] == EZ_CMD_COPY) {

				uint32_t key_offset = scratch[3] |
					scratch[4] << 8 |
					scratch[5] << 16 |
					scratch[6] << 24;

				uint8_t chunk_size = scratch[7];

				if (chunk_size > 128) {
					printf("bad chunk size\r\n");
					scratch[2] = 0;
					return;
				}

				printf(" writing %d bytes at offset %lu\r\n",
					chunk_size, key_offset);

				uint8_t kbuf[128];
				memcpy(kbuf, &scratch[8], chunk_size);
				flash_write(kbuf, key_offset, chunk_size);
				scratch[2] = 0x01;

			}

			if (scratch[2] == EZ_CMD_IDENTIFY) {

				uint8_t identity = scratch[3];
				int r = ez_identify(identity);

				if (r == 0 && identity == 0) {
					key_gen = 0;
					do_key_gen = 1;
				}

				scratch[2] = (r == 0);

			}

			if (scratch[2] == EZ_CMD_META_LOAD) {

				uint8_t metadata[32];

				int r = ez_find_current_metadata(metadata);

				scratch[2] = (r >= 0);
				memcpy(&scratch[3], metadata, 32);

			}

			if (scratch[2] == EZ_CMD_RAND) {

			//	printf("CMD: RAND\r\n");

				uint8_t random_bytes[32];


			//	printf("get_random\r\n");
				int r = atsha204a_get_random(random_bytes);

				scratch[2] = (r == 0);

				if (r == 0) {
//					printf("Random bytes:\r\n");
					for(int i=0;i<32;i++) {
//						printf("%02X ", random_bytes[i]);
						scratch[3+i] = random_bytes[i];
					}
//					printf("\r\n");
				} else {
					printf("ATSHA204A error: %d\r\n", r);
					// error could be due to sleeping
					printf("wake\r\n");
					atsha204a_wake();
				}

			}

			if (scratch[2] == EZ_CMD_ERASE) {

				if (ez_erase() == 0)
					scratch[2] = 1;
				else
					scratch[2] = 0;

			}

			if (scratch[2] == EZ_CMD_ENCRYPT) {

				int id = ez_identity();
				uint32_t send_ptr = ez_send_ptr();
				uint32_t flash_addr = send_ptr;
				uint8_t len = scratch[3];

				if (id < 0 || send_ptr == 0xffffffff) {
					scratch[2] = 0;
					return;
				}

				if (id == 1) flash_addr |= 0x200000;

				uint32_t offset = scratch[4] |
					scratch[5] << 8 |
					scratch[6] << 16 |
					scratch[7] << 24;

				flash_addr += offset;

				printf("encrypting\r\n");
				printf(" id: %02X\r\n", id);
				printf(" send_ptr: %08X\r\n", send_ptr);
				printf(" offset: %08X\r\n", offset);
				printf(" flash_addr: %08X\r\n", flash_addr);
				printf(" len: %02X\r\n", len);

				uint8_t kbuf[256];
				flash_read(kbuf, flash_addr, len);

				printf(" kbuf: ");
				for(int i = 0; i < len; i++) {
					printf("%02X ", kbuf[i]);
				}
				printf("\r\n");

				// return the base send_ptr
				scratch[4] = (send_ptr >> 24) & 0xff;
				scratch[5] = (send_ptr >> 16) & 0xff;
				scratch[6] = (send_ptr >> 8) & 0xff;
				scratch[7] = send_ptr & 0xff;

				// encrypt chunk
				for (int i = 0 ; i < len; i++) {
					scratch[8+i] = scratch[8+i] ^ kbuf[i];
				}

				scratch[2] = 1;

			}

			if (scratch[2] == EZ_CMD_DECRYPT || scratch[2] == EZ_CMD_DECRYPT_SELF)
			{

				int id = ez_identity();
				uint32_t flash_addr;
				uint8_t len = scratch[3];

				if (id != 0 && id != 1) {
					scratch[2] = 0;
					return;
				}

				if (scratch[2] == EZ_CMD_DECRYPT_SELF) {
					// use our own key
					if (id == 0) flash_addr = 0x000000;
					else flash_addr = 0x200000;
				} else {
					// use identity-opposite key
					if (id == 0) flash_addr = 0x200000;
					else flash_addr = 0x000000;
				}

				uint32_t offset = scratch[4] |
					scratch[5] << 8 |
					scratch[6] << 16 |
					scratch[7] << 24;

				flash_addr += offset;

				printf("decrypting\r\n");
				printf(" id: %02X\r\n", id);
				printf(" offset: %08X\r\n", offset);
				printf(" flash_addr: %08X\r\n", flash_addr);
				printf(" len: %02X\r\n", len);

				uint8_t kbuf[256];
				flash_read(kbuf, flash_addr, len);

				printf(" kbuf: ");
				for(int i = 0; i < len; i++) {
					printf("%02X ", kbuf[i]);
				}
				printf("\r\n");

				// decrypt chunk
				for (int i = 0 ; i < len; i++) {
					scratch[8+i] = scratch[8+i] ^ kbuf[i];
				}

				scratch[2] = 1;

			}

			if (scratch[2] == EZ_CMD_INC) {

				uint32_t send_ptr_inc = scratch[3] |
					scratch[4] << 8 |
					scratch[5] << 16 |
					scratch[6] << 24;

				printf("incrementing send_ptr by %lu", send_ptr_inc);

				ez_update_meta(send_ptr_inc, false);

				scratch[2] = 1;

			}

			if (scratch[2] == EZ_CMD_LOCK) {

				printf("scan\r\n");
				i2c_scan();

				printf("begin factory lock\r\n");
				int r = atsha204a_factory_lock();

				scratch[2] = (r == 0);

			}

			if (scratch[2] == EZ_CMD_DUMP_CONFIG) {
				printf("CMD: DUMP_CONFIG\r\n");
    
				int result = atsha204a_dump_config();
    
				if (result == 0) {
					scratch[2] = 1;  // Success
				} else {
					scratch[2] = 0;  // Failure
					scratch[3] = result;  // Error code
					printf("Failed to dump config (error %d)\r\n", result);
				}
			}

			// LED off
			GPIOD->BSHR = (1<<(16+LED));


			scratch[1] = 0x01;	// this means response

			start = 0;
		}

		if (do_key_gen) {
			ez_generate_keys();
		}

	}
}


// Microsecond delay
void delay_us(uint32_t us) {
    volatile uint32_t count = us * 12;
    while(count--);
}

void i2c_init(uint32_t pclk_mhz, uint32_t speed_hz)
{
    printf("Initializing correct open-drain I2C...\r\n");
    
    RCC->APB2PCENR |= RCC_APB2Periph_GPIOC;

    // CRITICAL: Set output data to 1 BEFORE configuring as open-drain
    GPIOC->BSHR = (1 << I2C_SDA) | (1 << I2C_SCL);
    
    // Configure as open-drain outputs
    GPIOC->CFGLR &= ~(0xF << (4*I2C_SDA));
    GPIOC->CFGLR |= (GPIO_Speed_50MHz | GPIO_CNF_OUT_OD) << (4*I2C_SDA);
    GPIOC->CFGLR &= ~(0xF << (4*I2C_SCL));
    GPIOC->CFGLR |= (GPIO_Speed_50MHz | GPIO_CNF_OUT_OD) << (4*I2C_SCL);
    
    delay_us(100);
    printf("Open-drain I2C initialized\r\n");
}

// Release line (set ODR bit = 1, pin goes Hi-Z, pulled high by resistor)
static void sda_release(void) {
    GPIOC->BSHR = (1 << I2C_SDA);
}

static void scl_release(void) {
    GPIOC->BSHR = (1 << I2C_SCL);
}

// Pull line low (set ODR bit = 0, pin actively sinks current)
static void sda_low(void) {
    GPIOC->BSHR = (1 << (16+I2C_SDA));
}

static void scl_low(void) {
    GPIOC->BSHR = (1 << (16+I2C_SCL));
}

// Read line state
static bool sda_read(void) {
    return (GPIOC->INDR >> I2C_SDA) & 1;
}

static bool scl_read(void) {
    return (GPIOC->INDR >> I2C_SCL) & 1;
}

// Wait for SCL to go high (clock stretching support)
static void scl_wait_high(void) {
    uint32_t timeout = 10000;
    while(!scl_read() && timeout--) {
        delay_us(1);
    }
}

static void i2c_start(void)
{
    // Ensure both lines are released (idle state)
    sda_release();
    scl_release();
    delay_us(I2C_DELAY_US);
    
    // START: SDA goes low while SCL is high
    sda_low();
    delay_us(I2C_DELAY_US);
    scl_low();
    delay_us(I2C_DELAY_US);
}

static void i2c_stop(void)
{
    // Ensure SCL is low
    scl_low();
    delay_us(I2C_DELAY_US);
    
    // SDA low (if not already)
    sda_low();
    delay_us(I2C_DELAY_US);
    
    // STOP: SCL high then SDA high
    scl_release();
    scl_wait_high();  // Wait for clock stretching
    delay_us(I2C_DELAY_US);
    sda_release();
    delay_us(I2C_DELAY_US);
}

static bool i2c_write_byte(uint8_t byte)
{
    // Send 8 bits, MSB first
    for(int i = 7; i >= 0; i--) {
        // Set data bit while SCL is low
        if(byte & (1 << i)) {
            sda_release();  // Logic 1: release SDA
        } else {
            sda_low();      // Logic 0: pull SDA low
        }
        delay_us(I2C_DELAY_US);
        
        // Clock pulse
        scl_release();
        scl_wait_high();  // Wait for clock stretching
        delay_us(I2C_DELAY_US);
        scl_low();
        delay_us(I2C_DELAY_US);
    }
    
    // Read ACK bit
    sda_release();  // Release SDA for slave to control
    delay_us(I2C_DELAY_US);
    
    scl_release();
    scl_wait_high();  // Wait for clock stretching
    delay_us(I2C_DELAY_US);
    
    // Read ACK (0 = ACK, 1 = NACK)
    bool ack = !sda_read();
    
    scl_low();
    delay_us(I2C_DELAY_US);
    
    return ack;
}

static uint8_t i2c_read_byte(bool send_ack)
{
    uint8_t byte = 0;
    
    // Release SDA to let slave drive it
    sda_release();
    
    // Read 8 bits, MSB first
    for(int i = 7; i >= 0; i--) {
        delay_us(I2C_DELAY_US);
        
        // Clock high
        scl_release();
        scl_wait_high();  // Wait for clock stretching
        delay_us(I2C_DELAY_US);
        
        // Sample data bit
        if(sda_read()) {
            byte |= (1 << i);
        }
        
        // Clock low
        scl_low();
        delay_us(I2C_DELAY_US);
    }
    
    // Send ACK/NACK
    if(send_ack) {
        sda_low();      // ACK: pull SDA low
    } else {
        sda_release();  // NACK: release SDA
    }
    delay_us(I2C_DELAY_US);
    
    // Clock pulse for ACK/NACK
    scl_release();
    scl_wait_high();
    delay_us(I2C_DELAY_US);
    scl_low();
    delay_us(I2C_DELAY_US);
    
    return byte;
}

int i2c_write(uint8_t addr, const uint8_t *data, uint8_t len)
{
    i2c_start();
    
    // Send address with write bit (0)
    if(!i2c_write_byte(addr << 1)) {
        i2c_stop();
        return -1; // Address NACK
    }
    
    // Send data bytes
    for(uint8_t i = 0; i < len; i++) {
        if(!i2c_write_byte(data[i])) {
            i2c_stop();
            return -2; // Data NACK
        }
    }
    
    i2c_stop();
    return 0;
}

int i2c_read(uint8_t addr, uint8_t *data, uint8_t len)
{
    if(len == 0) return 0;
    
    i2c_start();
    
    // Send address with read bit (1)
    if(!i2c_write_byte((addr << 1) | 1)) {
        i2c_stop();
        return -1; // Address NACK
    }
    
    // Read data bytes
    for(uint8_t i = 0; i < len; i++) {
        bool send_ack = (i < len - 1); // ACK all bytes except last
        data[i] = i2c_read_byte(send_ack);
    }
    
    i2c_stop();
    return 0;
}

void i2c_scan(void)
{
    printf("Scanning I2C bus (bit-bang)...\r\n");
    int found_count = 0;
    
    for(uint8_t addr = 0x08; addr < 0x78; addr++) {
        i2c_start();
        
        if(i2c_write_byte(addr << 1)) {
            printf("Device found at address 0x%02X\r\n", addr);
            found_count++;
        }
        
        i2c_stop();
        delay_us(100); // Small delay between attempts
    }
    
    printf("I2C scan complete: %d devices found\r\n", found_count);
}


// --

static uint16_t atsha_crc(const uint8_t *data, uint8_t len)
{
    uint16_t crc = 0;
    
    for(uint8_t i = 0; i < len; i++) {
        for(uint8_t shift = 0x01; shift > 0x00; shift <<= 1) {
            uint8_t data_bit = (data[i] & shift) ? 1 : 0;
            uint8_t crc_bit = crc >> 15;
            crc <<= 1;
            if((data_bit ^ crc_bit) != 0) {
                crc ^= 0x8005;
            }
        }
    }
    
	return crc;
}

void atsha204a_wake(void)
{
    printf("waking\r\n");
    
    // Standard wake sequence
    sda_release();
    scl_release();
    Delay_Ms(5);
    
    scl_release();
    sda_low();
    delay_us(100);
    sda_release();
    Delay_Ms(10);
   
    uint8_t wordaddr = 0x00;
    if (i2c_write(ATSHA204A_I2C_ADDR, &wordaddr, 1) != 0) {
        printf("Wake: failed to set read pointer (write 0x00)\r\n");
        return;
    }
 
    // CRITICAL: Read and consume the wake token
    uint8_t wake_token[4];
    if(i2c_read(ATSHA204A_I2C_ADDR, wake_token, 4) == 0) {
        printf("Wake token: %02X %02X %02X %02X\r\n", 
               wake_token[0], wake_token[1], wake_token[2], wake_token[3]);
        
        // Verify it's the expected wake token
//        if(wake_token[0] == 0x04 && wake_token[1] == 0x11) {
//            printf("Valid wake token received\r\n");
//        } else {
//            printf("Unexpected wake token\r\n");
//        }
    } else {
        printf("Failed to read wake token\r\n");
    }
    
//    printf("Wake sequence complete\r\n");
}

// Now try reading config after properly handling wake token
void read_config_properly(void)
{
    printf("Reading config after proper wake token handling...\r\n");
    
    atsha204a_wake();
    
    // Reset address counter
    uint8_t reset_addr = 0x00;
    if(i2c_write(ATSHA204A_I2C_ADDR, &reset_addr, 1) == 0) {
        // Now read actual config data
        uint8_t config_data[4];
        if(i2c_read(ATSHA204A_I2C_ADDR, config_data, 4) == 0) {
            printf("Config word 0: %02X %02X %02X %02X\r\n", 
                   config_data[0], config_data[1], config_data[2], config_data[3]);
            
            // Check for expected serial number prefix
            if(config_data[0] == 0x01 && config_data[1] == 0x23) {
                printf("Found expected serial number prefix!\r\n");
            }
        }
    }
}

int atsha204a_get_random(uint8_t *out32)
{
  //  printf("Getting random data...\r\n");
    
    // Build RANDOM command
    uint8_t cmd[7];
    cmd[0] = 0x07;   // count
    cmd[1] = 0x1B;   // RANDOM opcode
    cmd[2] = 0x00;   // param1 (0x00 = automatic seed update)
    cmd[3] = 0x00;   // param2 LSB
    cmd[4] = 0x00;   // param2 MSB
    uint16_t crc = atsha_crc(cmd, 5);
    cmd[5] = crc & 0xFF;
    cmd[6] = crc >> 8;

    // Send with command word address
    uint8_t txbuf[8];
    txbuf[0] = 0x03;
    memcpy(&txbuf[1], cmd, 7);
    
    if(i2c_write(ATSHA204A_I2C_ADDR, txbuf, 8) != 0) {
        printf("Command write failed\r\n");
        return -1;
    }

    Delay_Ms(50);

    // Try reading response directly without setting address first
    uint8_t rxbuf[35];

        // Device may have gone to sleep - try waking and reading
     //   printf("Device may be asleep, trying wake...\r\n");
     //   atsha204a_wake();
        
        // Set read pointer
        uint8_t wordaddr = 0x00;
        if(i2c_write(ATSHA204A_I2C_ADDR, &wordaddr, 1) != 0) {
            printf("Address write failed after wake\r\n");
            return -2;
        }
        
        int read_result = i2c_read(ATSHA204A_I2C_ADDR, rxbuf, 35);
        if(read_result != 0) {
            printf("Read failed after wake: %d\r\n", read_result);
            return -3;
       }

    // Check response length
    if(rxbuf[0] != 0x23) {
        if(rxbuf[0] == 0x04) {
            printf("Error response: 0x%02X\r\n", rxbuf[1]);
            return -10;
        }
        printf("Unexpected length: 0x%02X\r\n", rxbuf[0]);
        return -4;
    }

    // Verify CRC
    uint16_t resp_crc = rxbuf[33] | (rxbuf[34] << 8);
    uint16_t calc_crc = atsha_crc(rxbuf, 33);
//    printf("Response CRC: 0x%04X, Calculated: 0x%04X\r\n", resp_crc, calc_crc);
    
    if(resp_crc != calc_crc) {
        printf("CRC mismatch!\r\n");
        return -5;
    }

    // Copy random bytes
    memcpy(out32, &rxbuf[1], 32);

 //   printf("Successfully got 32 random bytes!\r\n");
    return 0;
}
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

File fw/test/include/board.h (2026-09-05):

/*
 * board.h -- Einszeit V1 (RP2350A) board definition
 *
 * Pin assignment supplied by the hardware author. Both SPI buses land on
 * their native hardware SPI functions, so no PIO is required:
 *
 *   GPIO18 = SPI0 SCK   GPIO19 = SPI0 TX   GPIO20 = SPI0 RX   GPIO21 = SPI0 CSn
 *   GPIO26 = SPI1 SCK   GPIO27 = SPI1 TX   GPIO28 = SPI1 RX   GPIO29 = SPI1 CSn
 *
 * Chip selects are driven as plain GPIO so that multi-byte transactions can
 * hold CS low across several spi_write_blocking() calls.
 */

/*
 * EZ-SEC-001 traceability (see docs/EZ-TEST-TRACEABILITY.md):
 *   SEC-HW-003  firmware storage and key data storage share no medium:
 *               firmware is in QSPI flash, key data is on the microSD.
 *   SEC-HW-002  SD_DET is the removal-detection input required by this
 *               requirement; its polarity is unconfirmed (gap G-02).
 *
 * Bench validation firmware. Not a production artifact.
 */
#ifndef EZ_BOARD_H
#define EZ_BOARD_H

#include "hardware/spi.h"

/* ---- FRAM (SPI0) ------------------------------------------------------- */
#define FRAM_SPI        spi0
#define FRAM_SCLK_PIN   18
#define FRAM_MOSI_PIN   19
#define FRAM_MISO_PIN   20
#define FRAM_SS_PIN     21      /* external 10K pull-up */

/* Conservative default; `fram bench` finds the real ceiling. */
#define FRAM_BAUD_DEFAULT   (8 * 1000 * 1000)
#define FRAM_BAUD_INIT      (1 * 1000 * 1000)

/* ---- microSD (SPI1) ---------------------------------------------------- */
#define SD_SPI          spi1
#define SD_DET_PIN      25
#define SD_SCLK_PIN     26      /* external 20K pull-up */
#define SD_MOSI_PIN     27      /* external 20K pull-up */
#define SD_MISO_PIN     28      /* external 20K pull-up */
#define SD_CSN_PIN      29      /* external 20K pull-up */

#define SD_BAUD_INIT    (400 * 1000)    /* card spec: 100-400 kHz during init */
#define SD_BAUD_DEFAULT (12 * 1000 * 1000)

/*
 * Card-detect polarity is not documented in the V1 schematic notes we were
 * given. `sd det` reports the raw level and watches for transitions so the
 * polarity can be determined empirically on the bench; set this once known.
 * 1 = pin reads low when a card is present (switch to GND, the common case).
 */
#ifndef SD_DET_ACTIVE_LOW
#define SD_DET_ACTIVE_LOW 1
#endif

/* ---- Status LED -------------------------------------------------------- */
#define LED_PIN         12

/* ---- Capture buffer ---------------------------------------------------- */
/*
 * RP2350A has 520 KB of SRAM. 192 KB = 1,572,864 bits, comfortably above the
 * 1,000,000-sample floor NIST SP 800-90B asks for on a binary source, and
 * also enough for a full 1000x1000 restart matrix (125 KB).
 */
#define EZ_CAP_MAX      (192u * 1024u)

#endif /* EZ_BOARD_H */

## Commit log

2025-11-02 add schematic pdf
2026-08-06 add v1 design & security spec
    [einszeit.kicad_pcb, einszeit.kicad_sch]
2026-08-23 update for manufacturing
    [mea.kicad_pcb, mea.kicad_sch]
2026-10-12 The V1 software stack, built and tested on the host and on V1 hardware.
    - core/: session metadata in F-RAM (TX/RX offsets, quarantine, event log),
    key generation with online entropy monitoring, buffered and streaming
    encryption, .SUM integrity tags verified before any key byte is used,
    the card mirror (two copies, failover, check, repair, background sync,
    health), spare copies in internal storage
    - ports/: FatFs key storage, the internal-flash key store (drive 0)
    - proto/, sw/ez, sw/vdev: the USB HID protocol with jobs on the second
    core, the new ez CLI, and a virtual device for testing
    - fw/einszeit: RP2350 firmware; production images einszeit_hid,
    einszeit_cdc and einszeit_comp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

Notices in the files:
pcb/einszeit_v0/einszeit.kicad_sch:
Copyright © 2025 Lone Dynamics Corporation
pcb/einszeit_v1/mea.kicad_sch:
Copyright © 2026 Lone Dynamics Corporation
